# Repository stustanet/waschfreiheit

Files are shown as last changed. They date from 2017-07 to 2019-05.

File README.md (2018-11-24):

# Waschen in Freiheit !!!
## Was ist das?
Dieses Projekt soll verhindern, dass die armen Studenten unnötig lange mit der Suche nach einer freien Waschmaschine verbringen. Dazu soll der Status aller Maschinen erfasst werden um diese dann online abfragbar zu machen. Will man dann Waschen kann man direkt zu einer freien Maschine laufen und muss nicht erst in jedem Waschraum vorbeischauen, nur um festzustellen, dass dieser schon belegt ist.

## Aufbau
Der aktuelle Plan sieh in etwa so aus:

```
                                     +---+
+---Raum------------------------+    |   |
|                               |    | F |
|  WM <- Sensor  \              |    | U |
|                 => Knoten <~~~|~~~>| N |
|  WM <- Sensor  /              |    | K |
|                               |    |   |
+-------------------------------+    |   |
                                     |   |     +--------+    +-----------+
                                     |   |<~~~>| Bridge |--->| Webserver |
+---Raum------------------------+    |   |     +--------+    +-----------+
|                               |    |   |
|  WM <- Sensor  \              |    |   |
|                 => Knoten <~~~|~~~>|   |
|  WM <- Sensor  /              |    |   |
|                               |    |   |
+-------------------------------+    |   |
                                     |   |
                                     |   |
+---Raum------------------------+    |   |
|                               |    |   |
|  WM <- Sensor ===> Knoten <~~~|~~~>|   |
|                               |    |   |
+-------------------------------+    |   |
                                     +---+
    
```

### Sensoren
Ein Sensor misst den Stromverbrauch einer Maschine. Dies geschieht über einen Hallsensor am Stromkabel.

### Knoten
Ein Knoten besteht aus einem Mikroprozessor (STM32F103C8T6 (V1) oder STM32F401RBT6(V2), Kleiner 32bit ARM) und einem 433Mhz Funkchip (Sx1276, LoRa Modulation).
An einen Knoten sind ein oder mehrere Sensoren angeschlossen. Die Sensordaten werden dann ausgewertet und bei einer Statusänderung wird ein Signal über die Funkschnittstelle gesendet.
Außerdem ist es die Aufgabe eines Knotens Nachrichten anderer Knoten weiterzuleiten, diese bilden quasi ein Mesh Netzwerk.

### Bridge
Es gibt im ganzen System genau eine Bridge (Gateway, Master Node), diese besteht aus einem Funkteil und einem Raspi. Die Aufgabe der Bridge ist es die Statusänderungen vom Mesh Netzwerk zu empfangen und diese dann per IP an einen Webserver weiterzuleiten, der diese dann anzeigt. Zusätzlich verwaltet die Bridge das Netzwerk und die Sensorparameter.

### Webserver
Der Webserver bekommt die Daten von der Bridge und zeigt den aktuellen Status an.

## Statuserkennung
Die Statuserkennung basiert auf Messwerten, die ein am Stromkabel befestigter Hall-Sensor liefert.
Um aus diesen Werten schlussendlich zu erkennen ob eine Maschine in Benutzung ist, durchläuft das Signal eine Reihe von Filtern.

### Analoger Teil
#### Wechselspannungs-Verstärker
Zuerst wird das Signal vom Hall-Sensor verstärkt. Der Verstärker hat für DC einen Verstärkungsfaktor von 1, es werden also nur Änderungen verstärkt.
#### Tiefpass
Bevor das Signal vom ADC digitalisiert wird, wird es mit einem RC-Filter geglättet. Dieser Tiefpass darf nicht zu träge sein, eine höhere Trägheit die Amplitude verringert.

### Digitaler Filter, Stufe 1 (Input)
Die erste Stufe bekommt die Messwerte des ADCs, sie wird für jede Messung einmal aufgerufen.
#### Absolutwertbestimmung
Da das Signal eine Wechselspannung mit dem Mittelpunkt von ca. der halben Betriebsspannung ist, muss zuerst der Absolutwert (Abweichung vom Mittelwert) bestimmt werden.
Dazu wird ein Mittelwert bestimmt, der für jeden Messwert, der drüber liegt um einen kleinen Wert erhöht wird (bzw. verringert wird, wenn der Messwert niedrieger ist).
Die Differenz zwischen dem Mittelwert und dem aktuellen Messwert ist der Absolutwert.
#### Digitaler Tiefpass
Der Absolutwert wird über einen Digitalen Tiefpass geglättet. Hier ist eine wesentlich stärkere Glättung möglich als vor dem Absolutwertfilter, da keine Amplitude verloren geht.

### Digitaler Filter, Stufe 2 (Frames)
In bestimmten Abständen (Frames) wird der aktuelle Tiefpasswert der Stufe 1 an die Stufe 2 weitergegeben. Der Abstand ist die "Framesize"
Die Stufe 2 wird einmal pro Frame aktualisiert. Die letzten "Window Size" Frame-Werte werden gespeichert, aus diesen wird der aktuelle Wert des Filters berechnet.
#### Blockfilter (Consec reject filter)
Alle Werte die nicht größer als ein Grenzwert ("Reject Threshold") sind und nicht mind. "Reject Consec" Werte davor auch über dem Grenzwert liegen werden bei der Berechnung des aktuellen Wertes ignoriert.

Beispiel:
Angenommen der Threshold wäre 5 und der "Consec count" wäre 3, dann würden nur die markierten Werte verwendet werden.

    3 9 8 2 7 8 9 6 3 4 9 2 1 6 7 8 9 9 9 3 4 7 8 2
            ^ ^ ^ ^           ^ ^ ^ ^ ^ ^

#### Durchschnittswert
Der aktuelle Filterwert ist der Durchschnitt aller Werte im aktuellen Fenster. Werte die vom Blockfilter ignoriert werden gehen mit 0 in den Durchschnitt ein.
#### Interner Status
Abhängig vom aktuellen Filterwert und dem aktuellen internen Status wird anhand von festgelegten Grenzwerten bestimmt, ob ein Zustandsübergang stattfindet.
Bei einem Zustandsübergang wird ggf. die "Window Size" angepasst. Für jeden internen Zustand ist festgelegt, ob die Maschine in diesem Zustand belegt oder frei ist.
Nur Änderungen des Belegtzustandes werden über das Netzwerk gesendet.

## Ich will das complien!
* Ggf. ARM Toolchain installieren.
* Dieses Repo klonen.
* git submodule init
* git submodule update
* "make all" im Ordner firmware baut Master (V1 / V2), Sensor (V1 / V2) und den Bootloader (nur V2)

## Flashen
Es gibt eine Reihe verschiedener Möglichkeiten die Firmware zu flashen.
Manche sind nur auf V1 oder V2 verfügbar.

### ST-LINK
Die bequemste Möglichkeit diese Controller zu flashen ist ein ST-LINK. Dies ist ein spezieller Programmer / Debugger für ST Controller. Um einen ST-LINK zu verwenden muss OpenOCD installiert sein.

#### Benötigte Anschlüsse
Um mit einen ST-LINK zu flashen müssen folgende 3 / 4 Leitungen mit dem Board verbunden werden:
* GND
* SWIO
* SWCLK
* Ggf. 3.3V

Flashen geht dann einfach mit
```
Sensor V1
make flash_sv1

Sensor V2
make USE_BOOTLOADER=FALSE flash_sv2

Master V1
make flash_mv1

Master V2
make flash_mv2

Bootloader V2
make flash_blv2
```

### Serieller Bootloader
Das Board muss über ein Serielles Kabel mit dem PC verbunden werden.

Der flasher Tool stm32loader.py befindet sich als submodule in firmware/utils.

Das Kabel wird wie folgt angesteckt:
* RX von Kabel an TX vom Board
* TX von Kabel an RX vom Board
* GND an GND
* Ggf. die 5V von USB and die 5V(!) vom Board anschließen

Um das Board in den Bootloader Modus zu bringen:
#### V1
* Den BOOT0 Jumper auf 1 setzen
* Reset kurz drücken
* Nach dem Flashen den BOOT0 Jumper auf 0 zurüksetzen

#### V2
* Boot drücken und halten
* Reset kurz drücken
* Boot wieder loslassen

Zum flashen dann
```
Binary erstellen mit
arm-none-eabi-objcopy -I ihex -O binary <ELF> /tmp/image.bin

flashen mit
./stm32loader.py -p /dev/ttyUSB0 -evw /tmp/image.bin
```

### USB DFU Bootloader (Nur V2)

Dazu muss zuerst das tool dfu-util gebaut werden.
Dieses ist als submodule in firmware/utils eingebunden.

```
cd firmware/utils
./autogen.sh
./configure
make
```

Das Board wird dann über ein Micro-USB Kabel mit dem PC verbunden.
Um das Board in den Bootloader Modus zu bringen:
* Boot drücken und halten
* Reset kurz drücken
* Boot wieder loslassen

Dann sollte es sich am PC als DFU Gerät anmelden.
Zum flashen dann
```
Binary erstellen mit
arm-none-eabi-objcopy -I ihex -O binary <ELF> /tmp/image.bin

flashen mit
sudo ./dfu-util -a 0 -s 0x08000000:leave -D /tmp/image.bin
```

### USB Host Bootloader (Nur Sensor V2)
Der USB Host Bootloader ist ein eigener Bootloader für diese Boards, der es erlaubt ein Firmware image auf einen USB-Stick zu laden und dann ohne einen PC ein Update einzuspielen.
Um diesen zu verwenden, muss das Firmware Image für den Bootloader gebaut werden (ohne USE_BOOTLOADER=FALSE) und der Bootloader muss geflasht sein (das geht mit einer der anderen Methoden).

Auf einen FAT32 formatierten USB Stick müssen sich folgende Dateien befinden:
* FIRMWARE.BIN  Neue Firmware im Binärformat
* CHECKSUM.CRC  CRC32 Prüfsumme der Firmware

Diese beiden Dateien können bequem mit make_boot_files.sh in firmware/utils aus einer ELF erstellt werden.

Dann den Stick einfach an das Board anstecken und resetten. Die Eingangs-LEDs sollten während des Updates der Reihe nach in den Farben Grün, Violett, Rot und Gelb aufleuchten.
Nach dem Flashen wird das Programm normal gestartet.

Der USB Stick wird *nicht* erkannt, wenn dass Board über den Micro-USB Anschluss mit Strom versorgt wird.

### Flasher command (Nur V1)
Die V1 Boards haben einen integrierten Flash-Befehl mit dem die Firmware aus dem laufenden Betrieb heraus geupdated werden kann.
Da dazu nur die Serielle Schnittstelle benötigt wird und nicht extra ein Boot-Modus aktiviert werden muss ist dieser Modus praktisch um die alten Nodes zu flashen, da diese schlecht zu Öffnen sind.
Der Nachteil ist, dass sich der Flasher selbst überschreibt, d.h. sollte etwas schiefgehen, ist der Knoten über diesen Weg nicht erneut flashbar.

Das Tool zum flashen ist firmware/utils/flasher_v1.py

Zum flashen
```
Binary erstellen mit
arm-none-eabi-objcopy -I ihex -O binary <ELF> /tmp/image.bin

flashen mit
./flasher_v1.py /dev/ttyUSB0 /tmp/image.bin
```

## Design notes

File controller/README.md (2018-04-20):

# Waschen in Freiheit - Management Interface

This is the Waschmaschinen management interface implemented in python.
It takes care in setting up the network, monitoring the network, and, if
neccessary, recover it in order to keep all nodes running.

It is designed to connect directly via a serial interface to the master node.

## Getting started

Create a virtual environment and install the requirements into it.

```
python3 -m venv venv
. ./venv/bin/activate
pip install -r requirements.txt
```

Now set up the nodes as they are supposed to work within the json config.
The management node can now be started with: (set the config file and the
serial connection according to your local setup!)

```
python3 main.py --config ./nodes.json --serial /dev/ttyUSB0
```

Now the interface is booting up. Have fun!

## Testing

You do not have a real master at hand? Therefore we have a very simplified
tester that reacts like the real thing.
It exposes a serial interface via socat, feeding in one of three test cases:

- Everything is fine, your network will *just* work, always, be happy!
- Node 2 is broken! Oh noes! It will never respond to you.
- You network is really bad. 80% of all your messages will timeout. Deal wit it

These have proven quite valuable to evaluate network performance and possible
deadlocks before the real hardware (network setup time: 0.0016s vs. 40s)

## Configuring

The configuration is split into two types of files: the main config and the
sensor specifications.

### Main Config

Follow this example config:

```javascript
{
  // Number of times a retransmit should be tried before a node is assumed dead,
  // and a network recovery is started
  "retransmissionlimit": 3,
  // Time in seconds, how often a network check should be performed
  "networkcheckintervall": 600,
  // How much time does one step in the network take, at max (in seconds)
  "single_hop_timeout": 2,

  // Configuring the different nodes
  "nodes": [
    // Every setup _needs_ a node named 'MASTER', it will be used as entry point
    // into the route resolution.
    {
      // The ID given here has to match the hardware-id of the actual node!
      "id": 0,
      // This name is used for reference later
      "name":"MASTER",
      // What sensors are connected (not used on the master node)
      "channels": [],
      // Sample rate of the sensors (not used on the master node)
      "samplerate": 0,
      // How to reach which other node.
      "routes":{
        "HOUSEA-ROOM1":"HOUSEA-ROOM1",
      }
    },
    {
      // The ID given here has to match the hardware-id of the actual node!
      "id": 1,
      // This name is used for reference later (see it in the master-routing?)
      "name":"HOUSEA-ROOM1",
      // Samples taken for the connected sensors per second
      "samplerate": 500,
      // Which sensors are connected?
      "channels": [
        {
          // Channel Number 0 is always the left plug
          "number": 0,
          "name":"left",
          "model":"A",
          // additional sensor data for configuring the sensor
          "config": "sensor_normal.json"
        },
        {
          "number": 1,
          "name":"right",
          "model":"B",
          "config": "sensor_normal.json"
        }
      ],
      // How to reach back to the master
      "routes":{
        "MASTER":"MASTER",
      }
    },
  ]
}
```

### Sensor Config

The sensor configuration file describes the details coming from sensor and
machine.

```javascript
{
	"input_filter":
	{
		"mid_adjustment_speed": 20,
		"lowpass_weight": 50,
		"frame_size": 100
	},
	"transition_matrix": [
		[   0,    0,   80,    0],
		[ -24,    0,    0,  160],
		[ -48,    0,    0,  160],
		[   0,  -80,    0,    0]
	],
	"window_sizes": [
		150,
		1500,
		1500,
		1500
	],
	"reject_filter": {
		"threshold": 104,
		"consec_count": 15
	}
}
```

These need to be adjusted for any machine and sensor connected.

## Routing

The most important configuration to reach all nodes is routing.

Every message is routed independently, so the sending node has to know via
which gateway it can reach which node.

If you have a setup like this in your building, and you can only reach from ones
adjacent.

```
| - - - - |
| OG 30   |
| OG 20   |
| OG 10   |
| MASTER  |
| - - - - |
```

You have to configure for the master

```
{
  'OG 30':'OG 10',
  'OG 20':'OG 10',
  'OG 10':'OG 10'
}
```

that way you tell him, it can reach every room via `OG 10`.

If you did some tests, and fortunately can reach nodes `OG 10` and `OG 20` from master,
then you configure:

```
{
  'OG 30':'OG 20',
  'OG 20':'OG 20',
  'OG 10':'OG 10'
}
```

## Failure States

It is normal, that from time to time a message does not reach its destination
and the system therefore logs a lost message. thats why we do try it again.

If a node does not respond to multiple retries, we start reinitializing it
in the hope, that it just has had a hickup (like some power-outages).

If that does not succeed, we issue an error - because then it is most likely
that the node has died, or something is not fine with the RF.

In the case of multiple failures, always check in order of distance (in terms of
routes from the master), because nodes that live behind a gateway cannot be
reached, if the gateway is broken.

Since the nodes themselve assume they are dead or have forgotten their routes,
if they do not receive messages once in a while, the network should mostly be
self-healing.
Only if a node continues to be dead, a manual restart or replacement might be
required.

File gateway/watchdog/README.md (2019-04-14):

# Serial watchdog
This is a watchdog running on a Atmel/Microchip AVR microcontroller, that listens on a serial port for a specific watchdog reset message:
```
wdt_feed
```

This resets the internal watchdog timer.
Otherwise, if the watchdog timer expires, it sets an output to HIGH in order to reset a connected device.
Some time before the reset, a PREFAIL signal is asserted, in order to notifiy the connected device, that the reset by the watchdog is imminent.

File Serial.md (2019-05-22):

# Serielles Interface

## Allgemeine Befehle

#### routes DST1:HOP1,DST2:HOP2,...
Setzt die routen die vom Aktuellen Knoten verwendet werden.
* DSTn:HOPn Pakete für DSTn werden an HOPn weitergeleitet.

Dieser Befehl ist auf den Sensorknoten nur zu testzwecken verfügbar. Diese Knoten bekonnen ihre Routen normalerweie über das Netzwerk vom Master.

#### ping NODE\_ID
Sendet einen Echo-Request an einen Knoten.
* NODE\_ID Adresse des Knotens.

Damit der Reply auch ankommt, muss eine aus beiden Richtungen gültige Route existieren.

## Sensor
Der Sensor kennt aktuell nur einen Befehl:
#### config NODE\_ID KEY\_STATUS KEY\_CONFIG
Ändert die Netzwerk-Configuration eines Sensorknotens.
* NODE\_ID ist die Adresse dieses Knotens. Eine Adresse darf nur einmal vergeben werden.
* KEY\_STATUS ist der Gemeinsame Schlüssel der für den Status-Kanal verwendet wird.
* KEY\_CONFIG ist der Gemeinsame Schlüssel der für den Konfigurations-Kanal verwendet wird.
* Beide Schlüssel sind 16 Byte lang und werden als Hex angegeben.

## Master
Der Master spricht ein gemischtes (Mensch- und Maschinenlesbares) Protokoll.
Dazu gibt es zusätzlich zu den "normalen" Befehlen spezielle Nachrichten die vom Knoten gesendet werden um den Host über Statusänderungen und Ergebnisse von Befehlen zu informieren.
Diese werden im folgenden Updates genannt.
Es darf immer nur einen Ausstehenden Befehl pro Node geben, dieser muss erst ACK'ed werden (ACK update) bevor der Nächste gesendet wird.
Die einzigen Ausnahmen sind master\_routes, ping und connect.

### Befehle

#### connect NODE\_ID RETURN\_HOP TIMEOUT
Stellt eine Verbindung zu einem Knoten her.
* NODE\_ID Adresse des Knotens zu dem die Verbindung aufgebaut werden soll.
* RETURN\_HOP Erster Knoten auf dem Rückweg (Pfad von NODE\_ID zum Master). Dies wird als temporäre Route verwendet bis die vollständigen Routen gesetzt wurden.
* TIMEOUT Ist die länge des timeouts. Nach der angegebenen Zeit wird ds TIMEOUT Update gesendet und retransmit darf aufgerufen werden.

#### retransmit NODE\_ID
Sendet das letzte Paket für einen Knoten erneut.
* NODE\_ID Adresse des Knotens

Dies darf nur aufgerufen erden, nachdem ein Knoten einen TIMEOUT gemeldet hat.

#### reset\_routes NODE\_ID DST1:HOP1,DST2,HOP2,...
#### set\_routes NODE\_ID DST1:HOP1,DST2,HOP2,...
Setzt / Ändert die Routen eines Knotens. reset\_routes setzt dabei zuerst den Knoten (incl. aller Routen und Sensoreinstellungen) zurück. add\_routes ändert nur die bestehenden Routen.
* NODE\_ID Adresse des Knotens der Konfiguriert wird. Bevor ein Knoten konfiguriert wird, muss eine Verbindung (connect) aufgebaut werden.
* DSTn:HOPn Pakete für DSTn werden an HOPn weitergeleitet. Es können pro Aufruf maximal 20 Routen angegeben werden.

Die Route die bei connect angegeben wurde muss hier erneut spezifiziert werden.

#### configure\_sensor NODE\_ID CHANNEL INPUT\_FILTER ST\_MATRIX WND\_SIZES REJECT\_FILTER
Ändert die Konfiguration eines Sensors. Genauere Informationen zu den Parametern finden sich im state\_estimation haeder.
* NODE\_ID Adresse des Knotens der Konfiguriert wird.
* CHANNEL Nummer des Sensor-Kanals der Konfiguriert wrid.
* INPUT\_FILTER 3 Werte (uint16): MID\_ADJUSTMENT,LOWPASS\_WEIGHT,NUM\_SAMPLES
* ST\_MATRIX 12 Werte (int16), Bedingungen für Zustandsübergänge.
* WND\_SIZES 4 Werte (uint16, max 1536), Festergrößen in den entsperchenden Zuständen.
* REJECT\_FILTER 2 Werte (uint16) REJECT\_THRESHOLD,REJECT\_CONSEC

#### enable\_sensor NODE\_ID CHANNEL\_MASK SAMPLES\_PER\_SEC
Startet / Aktiviert die Sensoren.
* NODE\_ID Adresse des Knotens der Konfiguriert wird.
* CHANNEL\_MASK Bitfeld, ein gesetztes Bit steht für einen aktiven Sensor.
* SAMPLES\_PER\_SEC Sampling-Rate des ADCs, diese gilt für alle Sensoren.

#### raw\_frames NODE\_ID CHANNEL NUM\_OF\_FRAMES
Fragt Sensordaten von einem Knoten an. Das ist nur zum Kalibrieren des Sensors gedacht.
* NODE\_ID Adresse des Knotens.
* CHANNEL Sensorkanal
* NUM\_OF\_FRAMES Anzahl an Frames zum Senden.

#### authping NODE\_ID
Fragt an ob ein Knoten noch aktiv ist.
* NODE\_ID Adresse des Knotens.

### Updates / Signale
Updates haben das Prefix ### um diese leicht zu parsen.
#### ACK\<ID\>-\<CODE\>
Eine Netzwerk-Anfrage an Knoten ID wurde bestätigt. CODE ist der ACK-Code, dieser ist Abhängig vom Request. 0 oder 128 bedeuten, dass die Anfrage erfolgreich war.
Nach einem ACK kann an den Node ID der nächste Befehl gesendet werden.
#### ERR
Der letzte Befehl war ungültig. Es braucht nicht auf ein ACK gewartet werden.
#### TIMEOUT\<ID\>
Es ist ein Timeout aufgetreten. Es sollte deshalb bei Zeiten für diesen Knoten einen retransmit Aufruf geben. Dieser kann entweder direkt nach dem Timeout kommen oder zwischen durch kann auch noch anderes gemacht werden.
#### STATUS\<ID\>-\<STATUS\>
Statusupdate von Knoten ID. Status ist ein Bitfeld, ein gesetztes Bit steht für eine Aktive Maschine.
#### PEND\<ID\>
Ein PEND Signal kommt als direkte Antwort auf einen Befehl, falls ein Packet versendet wurde welches bestätigt werden muss. Daher folgt auf ein PEND immer ein ACK oder ein TIMEOUT.

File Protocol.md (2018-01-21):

# Nachrichten und Routing
## Übersicht
Die Schichten sind an das OSI Modell angelehnt.

### Physical Layer (Layer 1)
Für den Datentransport wird 433MHz Funk mit LoRa Modulation verwednet. Alle Knoten senden und empfangen auf der selben Frequenz.

### Data Link Layer (Layer 2)
Die Verwendeten Funkmdule (Sx127x) kümmern sich bereits um das Verpacken der Daten in Pakete. Jedes Paket besitzt eine CRC Prüfsumme und eine Längenangabe (unterschiedlich lange Pakete sind also möglich),

### Network / Routing Layer (Layer 3)

Jeder Knoten hat eine eindeutige Adresse, alle Pakete haben folgende drei Knoten-Adressen:
* Quelle
* Ziel
* Next-Hop

Die Quelladresse ist dabei die Adresse des ursprünglichen Senders, die Zieladresse die des finalen Ziels. Next-Hop ist die Adresse des Knotens, der dieses Paket empfangen soll um es dann entweder zu verarbeiten (Next-Hop == Ziel) oder weiterzuleiten (Ziel in der Routing-Tabelle suchen und mit dem / an den entsprechendem Next-Hop weitersenden).
Eine Adressse ist eine 8-bit Zahl.

### Payload type (Layer 4)
(Jetzt nicht mehr OSI)
Typ-ID der Payload.
Je nach Typ wird auch ein MAC über den Layer4 (type + data) + Source und Destiantion Adresse gebiltet.

### Payload data (Layer 5)
(optional)
Je nach Payload-Typ unterschiedliche Daten.

## Aufbau des Netzwerks
### Master node
Der Koordinator (Master) hat die Aufgabe das Netzwerk aufzubauen und zu verwalten und dient gleichzeitig als Gateway zwischen dem Funk-Netz und dem Internet.
Der Master besitzt normalerweise die Adresse 0, da diese für einen Sensor ungültig ist.
Das Routing ist (vorest) statisch, aber zentral verwaltet, d.h. der Master kennt alle Knoten (diese sind in seiner config festgelegt) und alle Routing-Tabelle der Knoten (ebenfalls aus config).
Zum Initialisieren des Netzes werden nacheinander die Knoten vom Master aus angesprochen und die Routing-Tabellen der Knoten konfiguriert. Diese Verbinung wird ggf. über bereits konfigurierte Knoten (wenn das Ziel weiter weg ist) geroutet.
Nach dieser Initialisierung hat jeder Knoten eine (hoffentlich gültige und sinvolle) Routing-Tabelle und weis somit wohin er eine Nachricht die bei ihn ankommt weiterleiten soll.

### Acknowledgements
Es gibt keine allgemeinen Acknowledgements, jedoch müssen Nachrihten die signiert sind bestätigt werden. Dazu wird ein signiertes Ack Paket zurück gesendet.

### Aufbau eines Layer 3 Pakets
Layer 3 ist das Routing-Layer und das niedrigste Layer um das sich der Node kümmert.
Wenn ein Paket weitergeleitet wird, wird nur der Next-Hop geändert und das Paket ansonsten unverändert erneut gesendet.

Die Zahl in Klammern ist die Bit-Anzahl des jeweiligen Feldes.

```
+--------------+
| Next-Hop (8) |
|--------------|
| Ziel     (8) |
|--------------|
| Quelle   (8) |
|--------------|
|              |
| Layer 4  (n) |
|              |
+--------------+
```

### Authentication Protocol
A und B besitzen einen gemeinsamen Geheimen Schlüssel. Eine Verbndung ist nur unidirektional, für eine Verbindung in die andere Richtung muss ein zweiter Kanal (mit einem anderen Schlüssle aufgebaut werden.)

A möchte eine Verbindung aufbauen um Daten nach B zu übertragen, sodass B sicher sein kann, dass diese von A kommen.
(z.B. A möchte die Konfiguration von B ändern).

```
A                                      B
|                                      |
|----------> REQ_NONCE, M ------------>|
|                                      |
|<--------- N, M, MAC(N, M) -----------|
|                                      |
|---- CMD, N + 1, MAC(CMD, N + 1) ---->|
|                                      |
|<--- ACK, N + 2, MAC(ACK, N + 2) -----|
|                                      |
|---- CMD, N + 3, MAC(CMD, N + 3) ---->|
|                                      |
|<--- ACK, N + 4, MAC(ACK, N + 4) -----|
|                                      |
                                      
```

### Aufbau eines Layer 4 Pakets
Anhand der Payload-ID wird entschieden was für Daten das Paket enthält und ob es eine MAC hat.
Die nonce in der Nachricht ist die letzten 4 bit der aktuellen nonce. Dies wird verwendet um retransmissions schnell
zu erkennen.

```
+---------------------*
| Payload-ID (8)      |
|---------------------|
|                     |
| Layer 5 / Daten (n) |
|                     |
|---------------------|
| [Nonce (4)]         |
|---------------------|
| [MAC (60)]          |
+---------------------+
```

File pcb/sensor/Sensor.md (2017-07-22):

Das Funktionsprinzip der Sensoren ist das einer Stromzange, die Messung beruht darauf, dass ein Stromdurchflossener Leiter ein Magnetfeld erzeugt welches dann von einem Hallsensor gemessen werden kann.
Dabei wird um das Kabel ein Ferritkern gelegt, dieser hat einen Spalt, in den dann der eigentliche Sensor gesteckt wird.

Als Sensoren werden die analogen Hallsensoren "49E" verwendet. Diese Sensoren sollten bei keinem Magnetfeld eine Ausgangsspannung von exakt der halben Betriebsspannung liefern. Wenn sind das Magnetfeld ändert, ändert sich auch die Ausgangsspannung (ca. 1.8 mV / G).
Damit mit diesen am ADC des Mikroprozessors auch bei geringen Strömen ein sinnvoller Ausschlag messbar ist muss das Ausgangssignal noch zusätzlich verstärkt werden.
Der aktuelle Entwurf für diesen Verstärker ist ein Wechselspannungsverstärker, der nur Änderungen verstärkt und für Gleichspannung einen Verstärkungsfaktor von 1 hat.
Das hat den Vorteil, dass eventuelle Offsets der Sensorspannung nicht so sehr stören, leider ist diese Konstruktion jedoch sehr empfindlich gegenüber Störungen auf der Versorgungsspannung, hier besteht also noch Verbesserungspotential.
Eine einfache Konstruktion, die die Differenz von der Sensorspannung und der halben Betriebsspannung verstärkt, ist allerdings nicht möglich, da die Sensoren nicht *genau* die halbe Betriebsspannung liefern, wenn kein Magnetfeld da ist.
Diese Abweichung ist so groß, dass diese (bei dem gewünschten Verstärkungsfaktor) nicht einfach in Software korrigierbar ist.

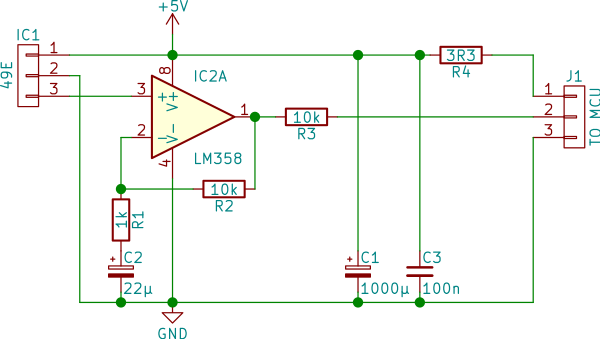
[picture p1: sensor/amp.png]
Schaltplan


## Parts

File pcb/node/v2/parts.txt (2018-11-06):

MCU: STM32F401RBT6
USB Switch: MIC2005A-1YM5-TR
Pluggable Terminal blocks

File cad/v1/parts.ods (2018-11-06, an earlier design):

# Räume | 4
Bauteileliste | #Pro raum | #Total | #Done | #Missing | Time/Part[h] | Time | Total printing time
ELEKTRONIK
Node-Platine | 1 | 4 | 3 | 1 | 2 | 2
Sensor-Platine | 2 | 8 | 8 | 0 | 1 | 0
3D PRINTS
SENSOR
Sensor-Bottom | 2 | 8 | 8 | 0 | 0,35 | 0 | 2,8
Sensor-Top | 2 | 8 | 8 | 0 | 1 | 0 | 8
Sensor-Wirecap | 2 | 8 | 8 | 0 | 0,25 | 0 | 2
Sensor-Wiresupport | 4 | 16 | 4 | 12 | 0,1 | 1,2 | 1,6
NODE
Node-Bottom | 1 | 4 | 3 | 1 | 2,25 | 2,25 | 9
Node Top | 1 | 4 | 3 | 1 | 4,5 | 4,5 | 18
Node LED Backplate | 1 | 4 | 4 | 0 | 0,75 | 0 | 3
Node LED Cover | 5 | 20 | 20 | 0 | 0,04 | 0 | 0,8
Wall distance | 3 | 12 | 12 | 0 | 0,04 | 0 | 0,48
 |  |  |  |  |  | 7,95 | 45,68
 |  |  |  |  |  | PER ROOM | 11,42

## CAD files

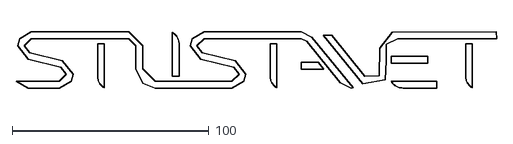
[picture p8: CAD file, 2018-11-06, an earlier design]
cad/v1/logo.dxf
244.2 x 28.5

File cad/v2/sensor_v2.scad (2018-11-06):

$fn=100;

epsilon = 0.003;

//TODO: Check params
power_cable_dia = 3.5;
ferrite_outer_dia = 10.4;
ferrite_depth = 5.3;
ferrite_width = 2.2;

pcb_size = [14, 11.5, 5];
pcb_cable_guide_width = 5;
pcb_cable_guide_extra_height = 4;
sensor_left_offset = 1;
sensor_height_offset = 2.3;
sensor_pin_size = [3, 0.8, 0.5];
sensor_head_size = [4.1, 3.2, 1.6];
sensor_head_z_pos = -0.3;

data_cable_dia = 4.1;
data_cable_x = 12;
data_cable_y = 5;
data_cable_zip_dist = -0.3;

base_sx = 21;
base_sy = 17;

base_border = [4, 2, 3.5];
base_edge_width = 1;
base_edge_heigth = 1;
base_cutout_x = 4;
base_cutout_y = 11;

top_thickness = 6;

zip_size = [1.4, 2.9];

// Derived parameters
pcb_to_sensor_center = [0, pcb_size[1], 0] + [sensor_left_offset + sensor_pin_size[0] / 2, sensor_pin_size[1], sensor_height_offset + sensor_head_z_pos] + [0, sensor_head_size[1] / 2, sensor_head_size[2] / 2];

ferrite_center = pcb_to_sensor_center - [ferrite_outer_dia / 2 - ferrite_width / 2, 0, 0];

base_size = [base_sx + base_border[0] * 2, base_sy + base_border[1] * 2, base_border[2] + ferrite_center[2]];

module ferrite()
{
    //difference()
    {
        cylinder(h = ferrite_depth, r = ferrite_outer_dia / 2, center = true);
        cylinder(h = ferrite_depth + epsilon, r = ferrite_outer_dia / 2 - ferrite_width, center = true);
    }
}

module power_cable()
{
    cylinder(h = 100, r = power_cable_dia / 2, center = true);
}

module pcb()
{
    
    cube(pcb_size);
    
    translate([0, 0, -pcb_cable_guide_extra_height / 2])
        cube([pcb_size[0], pcb_cable_guide_width, pcb_size[2] + pcb_cable_guide_extra_height]);
    translate([sensor_left_offset, pcb_size[1], sensor_height_offset])
    {
        cube(sensor_pin_size);
        translate([(sensor_pin_size[0] - sensor_head_size[0]) / 2, sensor_pin_size[1], sensor_head_z_pos])
        {
            cube(sensor_head_size);
        }
    }
}

module data_cable()
{
    cylinder(h = 100, r = data_cable_dia / 2);
}


module base_edge()
{
    translate([-epsilon/2, -epsilon/2, base_size[2] - base_edge_heigth + epsilon])
    {
        // normal edges
        translate([0, base_cutout_y - epsilon, 0])
            cube([base_edge_width + epsilon, base_size[1] - base_cutout_y + epsilon, base_edge_heigth]);
        
        translate([base_size[0] - base_edge_width, 0, 0])
            cube([base_edge_width + epsilon, base_size[1] + epsilon, base_edge_heigth]);
        
        translate([base_cutout_x - epsilon, 0, 0])
            cube([base_size[0] - base_cutout_x + epsilon, base_edge_width + epsilon, base_edge_heigth]);
        
        translate([0, base_size[1] - base_edge_width, 0])
            cube([base_size[0] + epsilon, base_edge_width + epsilon, base_edge_heigth]);
        
        // cutout edges
        translate([base_cutout_x - epsilon, 0, 0])
            cube([base_edge_width + epsilon, base_cutout_y, base_edge_heigth]);
        
        translate([base_edge_width, base_cutout_y - epsilon, 0])
            cube([base_cutout_x, base_edge_width + epsilon, base_edge_heigth]);
    }
}


module base()
{
    translate([pcb_size[0] - base_size[0] + base_border[0],
               -base_border[1],
               -base_border[2]])
    {
        difference()
        {
            cube(base_size);
            
            translate([-epsilon, -epsilon, -epsilon/2])
                cube([base_cutout_x, base_cutout_y, base_size[2] + epsilon]);
            
            base_edge();
        }
    }
}


module top()
{
    translate([pcb_size[0] - base_size[0] + base_border[0],
               -base_border[1],
               -base_border[2] + base_size[2]])
    {
        difference()
        {
            cube([base_size[0], base_size[1], top_thickness]);
            
            translate([-epsilon, -epsilon, -epsilon/2])
                cube([base_cutout_x, base_cutout_y, top_thickness + epsilon]);
        }
    }
        
    translate([pcb_size[0] - base_size[0] + base_border[0],
           -base_border[1],
           -base_border[2]])
    {
        base_edge();
    }
}


module zip_tie()
{
    translate([0, 0, -10])
    {
        cube([zip_size[0], zip_size[1], 25]);
    }
}

module bottom_only_zip_tie()
{
    translate([0, 0, ferrite_center[2] - 10 + epsilon])
    {
        cube([zip_size[0], zip_size[1], 10]);
    }
}

module zip_ties()
{
    translate([ferrite_center[0] - power_cable_dia, 3, 0]) zip_tie();
    translate([pcb_size[0] + 1, 3, 0]) zip_tie();
    
    translate([-9, ferrite_center[1] - zip_size[1] / 2, 0]) zip_tie();
    translate([5.5, ferrite_center[1] - zip_size[1] / 2, 0]) zip_tie();
    
    
    // zip ties for the data cable
    
    translate([data_cable_x - data_cable_dia / 2 - zip_size[0], ferrite_center[1] - zip_size[1] / 2, 0])
    {
        translate([-data_cable_zip_dist, 0, 0])
        bottom_only_zip_tie();
        
        translate([data_cable_dia + data_cable_zip_dist + zip_size[0], 0, 0]) bottom_only_zip_tie();
        
        // cutout in the top part for the data cable zip tie
        translate([0, 0, ferrite_center[2] + epsilon])
        cube([data_cable_dia + zip_size[0] * 2, zip_size[1], data_cable_dia / 2 + zip_size[0] + 1]);
    }
}


module components()
{
    pcb();

    translate(ferrite_center)
    rotate([90, 0, 0])
    {
        ferrite();
        power_cable();
    }
    
    translate([data_cable_x, data_cable_y, ferrite_center[2]])
    rotate([90, 0, 180])
    {
        data_cable();
    }
    
    zip_ties();
}


difference()
{
    base();
    %top();
    #components();
}

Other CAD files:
cad/v1/sensor_wall_plate.scad
cad/v1/cable.scad
cad/v1/casing.scad
cad/v1/distance_wall.scad
cad/v1/main_casing.scad

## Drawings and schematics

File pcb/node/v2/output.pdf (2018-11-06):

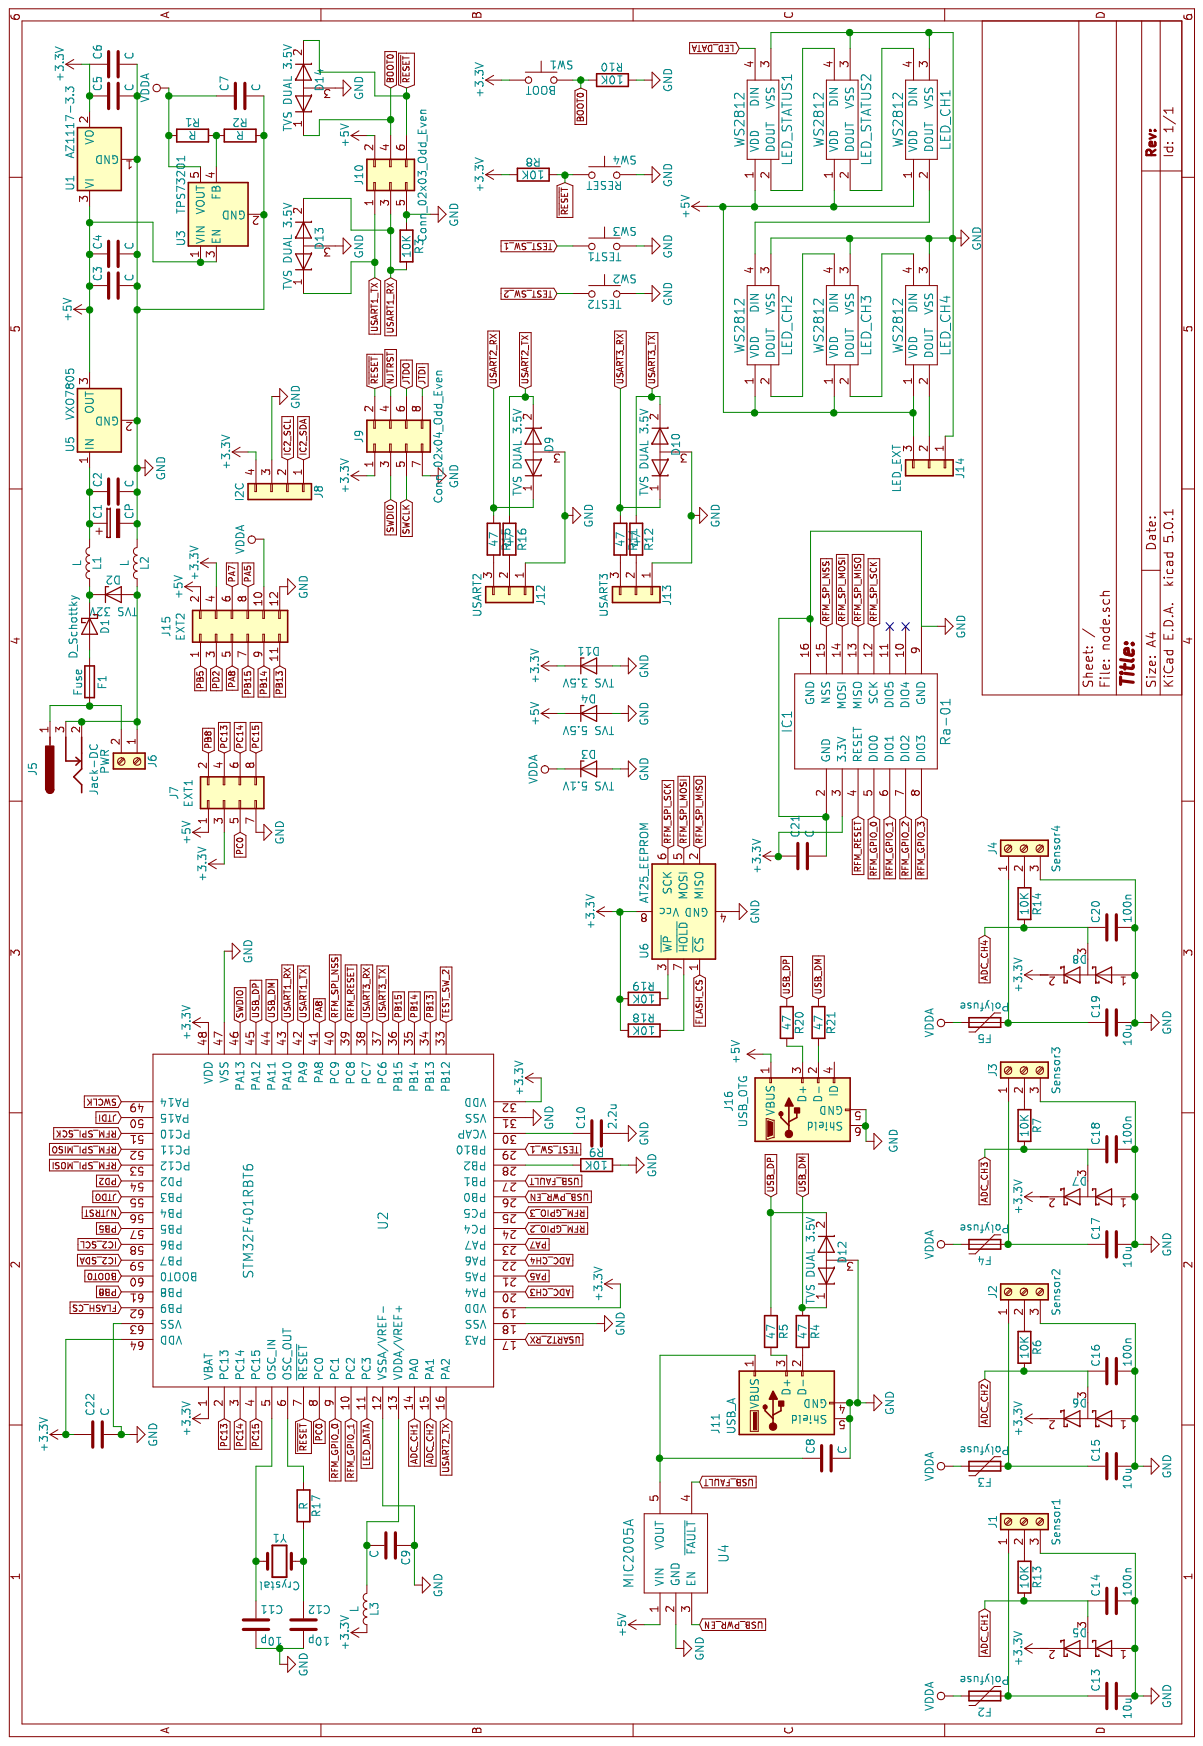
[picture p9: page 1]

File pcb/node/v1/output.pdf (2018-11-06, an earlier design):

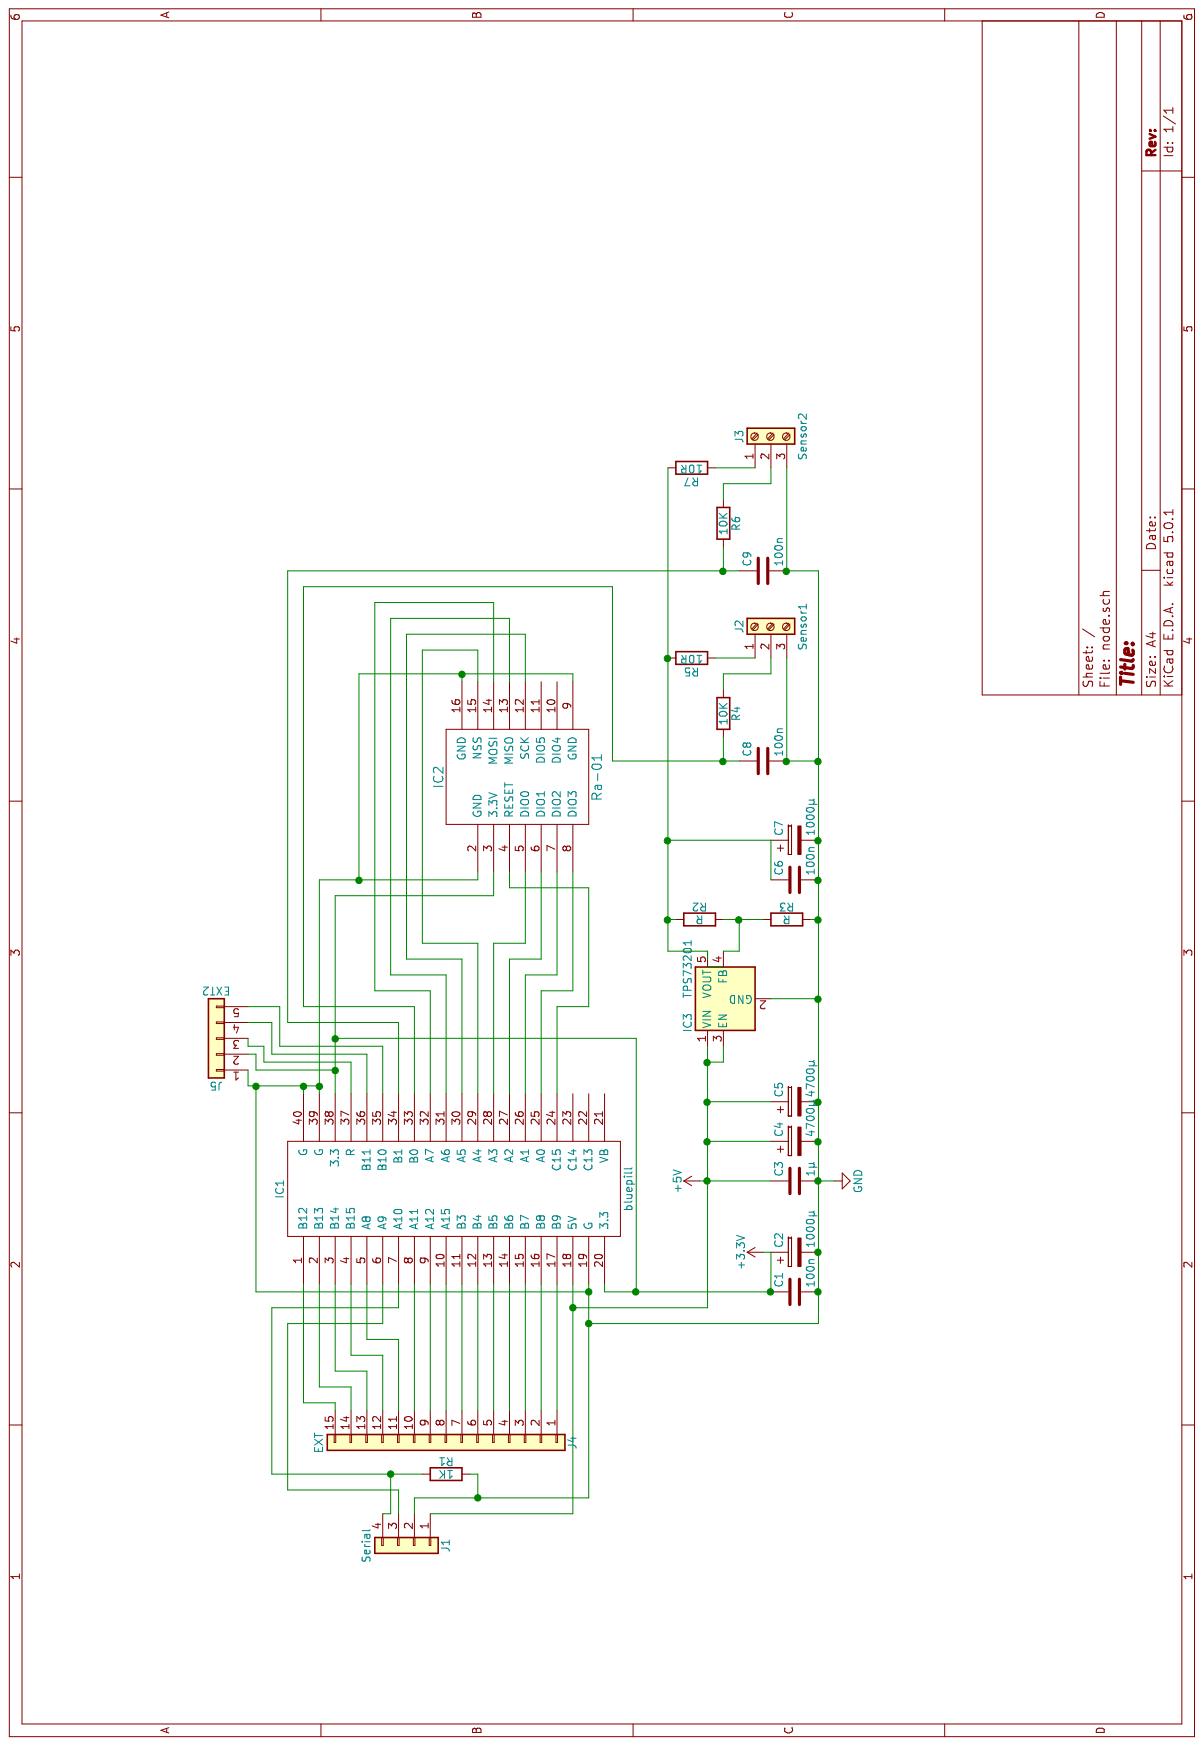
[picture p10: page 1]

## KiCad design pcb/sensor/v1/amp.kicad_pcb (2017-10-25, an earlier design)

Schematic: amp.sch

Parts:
C1: 1000µ; CP_Radial_D10.0mm_P5.00mm
C2: 22µ; CP_Radial_D5.0mm_P2.00mm
C3: 100n; C_Disc_D5.0mm_W2.5mm_P5.00mm
IC1: 49E; TO-92_Inline_Narrow_Oval
IC2: LM358; SOIC-8-N
J1: TO MCU; Pin_Header_Straight_1x03_Pitch2.54mm
R1: 1K; R_0805
R2: 10K; R_0805
R3: 4K7; R_0805
R4: 3R3; R_0805

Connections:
+5V: C1.1, C3.1, IC1.1, IC2.8 (V+), R4.2
GND: C1.2, C2.2, C3.2, IC1.2, IC2.4 (V-), J1.3
unnamed: C2.1, R1.2
unnamed: IC1.3, IC2.5 (+)
unnamed: IC2.6 (-), R1.1, R2.2
unnamed: IC2.7, R2.1, R3.2
unnamed: J1.1, R3.1
unnamed: J1.2, R4.1

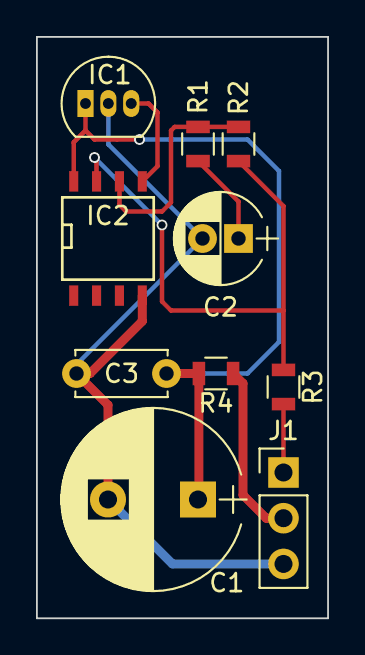
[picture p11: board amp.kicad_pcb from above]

Board: 2 copper layers, 16.2 x 32.3 mm, 10 parts (0 on the bottom side), 8 nets.

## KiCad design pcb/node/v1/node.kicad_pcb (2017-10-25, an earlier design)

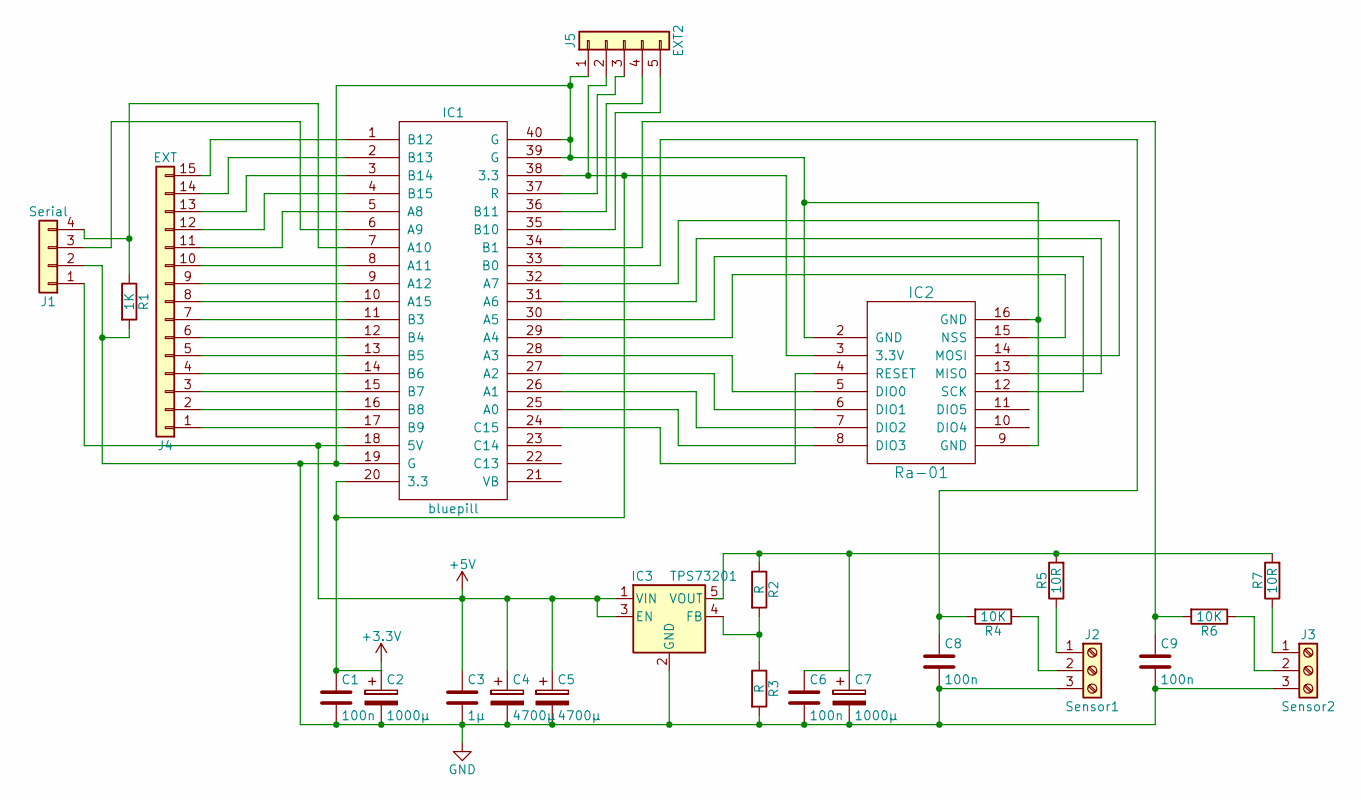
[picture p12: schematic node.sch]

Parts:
C1, C6, C8, C9: 100n; C_Disc_D5.0mm_W2.5mm_P2.50mm
C2, C7: 1000µ; CP_Radial_D10.0mm_P5.00mm
C3: 1µ; C_Disc_D7.5mm_W5.0mm_P5.00mm
C4, C5: 4700µ; CP_Radial_D12.5mm_P5.00mm
IC1: bluepill; DIP-40_W15.24mm
IC2: Ra-01
IC3: TPS73201; SOT-23-5
J1: Serial; Pin_Header_Straight_1x04_Pitch2.54mm
J2: Sensor1; TerminalBlock_Philmore_TB133_03x5mm_Straight
J3: Sensor2; TerminalBlock_Philmore_TB133_03x5mm_Straight
J4: EXT; Pin_Header_Straight_1x15_Pitch2.54mm
J5: EXT2; Pin_Header_Straight_1x05_Pitch2.54mm
R1: 1K; R_Axial_DIN0309_L9.0mm_D3.2mm_P12.70mm_Horizontal
R2, R3: R; R_0805
R4, R6: 10K; R_Axial_DIN0309_L9.0mm_D3.2mm_P12.70mm_Horizontal
R5, R7: 10R; R_Axial_DIN0309_L9.0mm_D3.2mm_P12.70mm_Horizontal

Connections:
+3V3: C1.1, C2.1, IC1.20 (3.3), IC1.38 (3.3), IC2.3 (3.3V), J5.2
+5V: C3.1, C4.1, C5.1, IC1.18 (5V), IC3.1 (VIN), IC3.3 (EN), J1.1
GND: C1.2, C2.2, C3.2, C4.2, C5.2, C6.2, C7.2, C8.2, C9.2, IC1.19 (G), IC1.39 (G), IC1.40 (G), IC2.2 (GND), IC2.9 (GND), IC2.16 (GND), IC3.2 (GND), J1.2, J2.3, J3.3, J5.1, R1.2, R3.2
unnamed: C6.1, C7.1, IC3.5 (VOUT), R2.1, R5.2, R7.2
unnamed: C8.1, IC1.33 (B0), R4.2
unnamed: C9.1, IC1.34 (B1), R6.2
unnamed: IC1.1 (B12), J4.15
unnamed: IC1.2 (B13), J4.14
unnamed: IC1.3 (B14), J4.13
unnamed: IC1.4 (B15), J4.12
unnamed: IC1.5 (A8), J4.11
unnamed: IC1.6 (A9), J1.3
unnamed: IC1.7 (A10), J1.4, R1.1
unnamed: IC1.8 (A11), J4.10
unnamed: IC1.9 (A12), J4.9
unnamed: IC1.10 (A15), J4.8
unnamed: IC1.11 (B3), J4.7
unnamed: IC1.12 (B4), J4.6
unnamed: IC1.13 (B5), J4.5
unnamed: IC1.14 (B6), J4.4
unnamed: IC1.15 (B7), J4.3
unnamed: IC1.16 (B8), J4.2
unnamed: IC1.17 (B9), J4.1
unnamed: IC1.24 (C15), IC2.4 (RESET)
unnamed: IC1.25 (A0), IC2.8 (DIO3)
unnamed: IC1.26 (A1), IC2.7 (DIO2)
unnamed: IC1.27 (A2), IC2.6 (DIO1)
unnamed: IC1.28 (A3), IC2.5 (DIO0)
unnamed: IC1.29 (A4), IC2.15 (NSS)
unnamed: IC1.30 (A5), IC2.12 (SCK)
unnamed: IC1.31 (A6), IC2.13 (MISO)
unnamed: IC1.32 (A7), IC2.14 (MOSI)
unnamed: IC1.35 (B10), J5.5
unnamed: IC1.36 (B11), J5.4
unnamed: IC1.37 (R), J5.3
unnamed: IC3.4 (FB), R2.2, R3.1
unnamed: J2.1, R5.1
unnamed: J2.2, R4.1
unnamed: J3.1, R7.1
unnamed: J3.2, R6.1

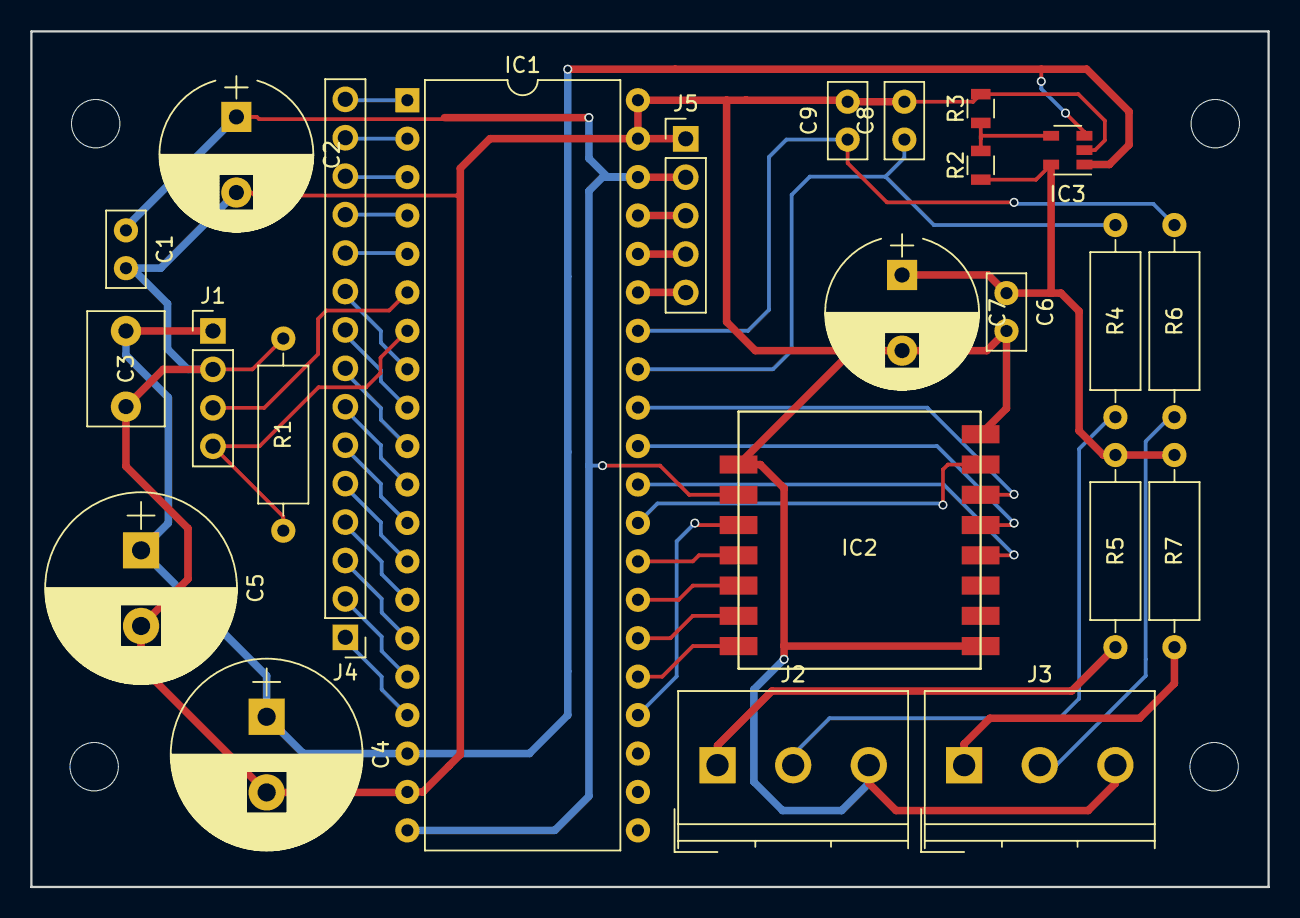
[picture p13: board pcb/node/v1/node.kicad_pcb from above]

Board: 2 copper layers, 81.8 x 56.5 mm, 24 parts (0 on the bottom side), 40 nets.

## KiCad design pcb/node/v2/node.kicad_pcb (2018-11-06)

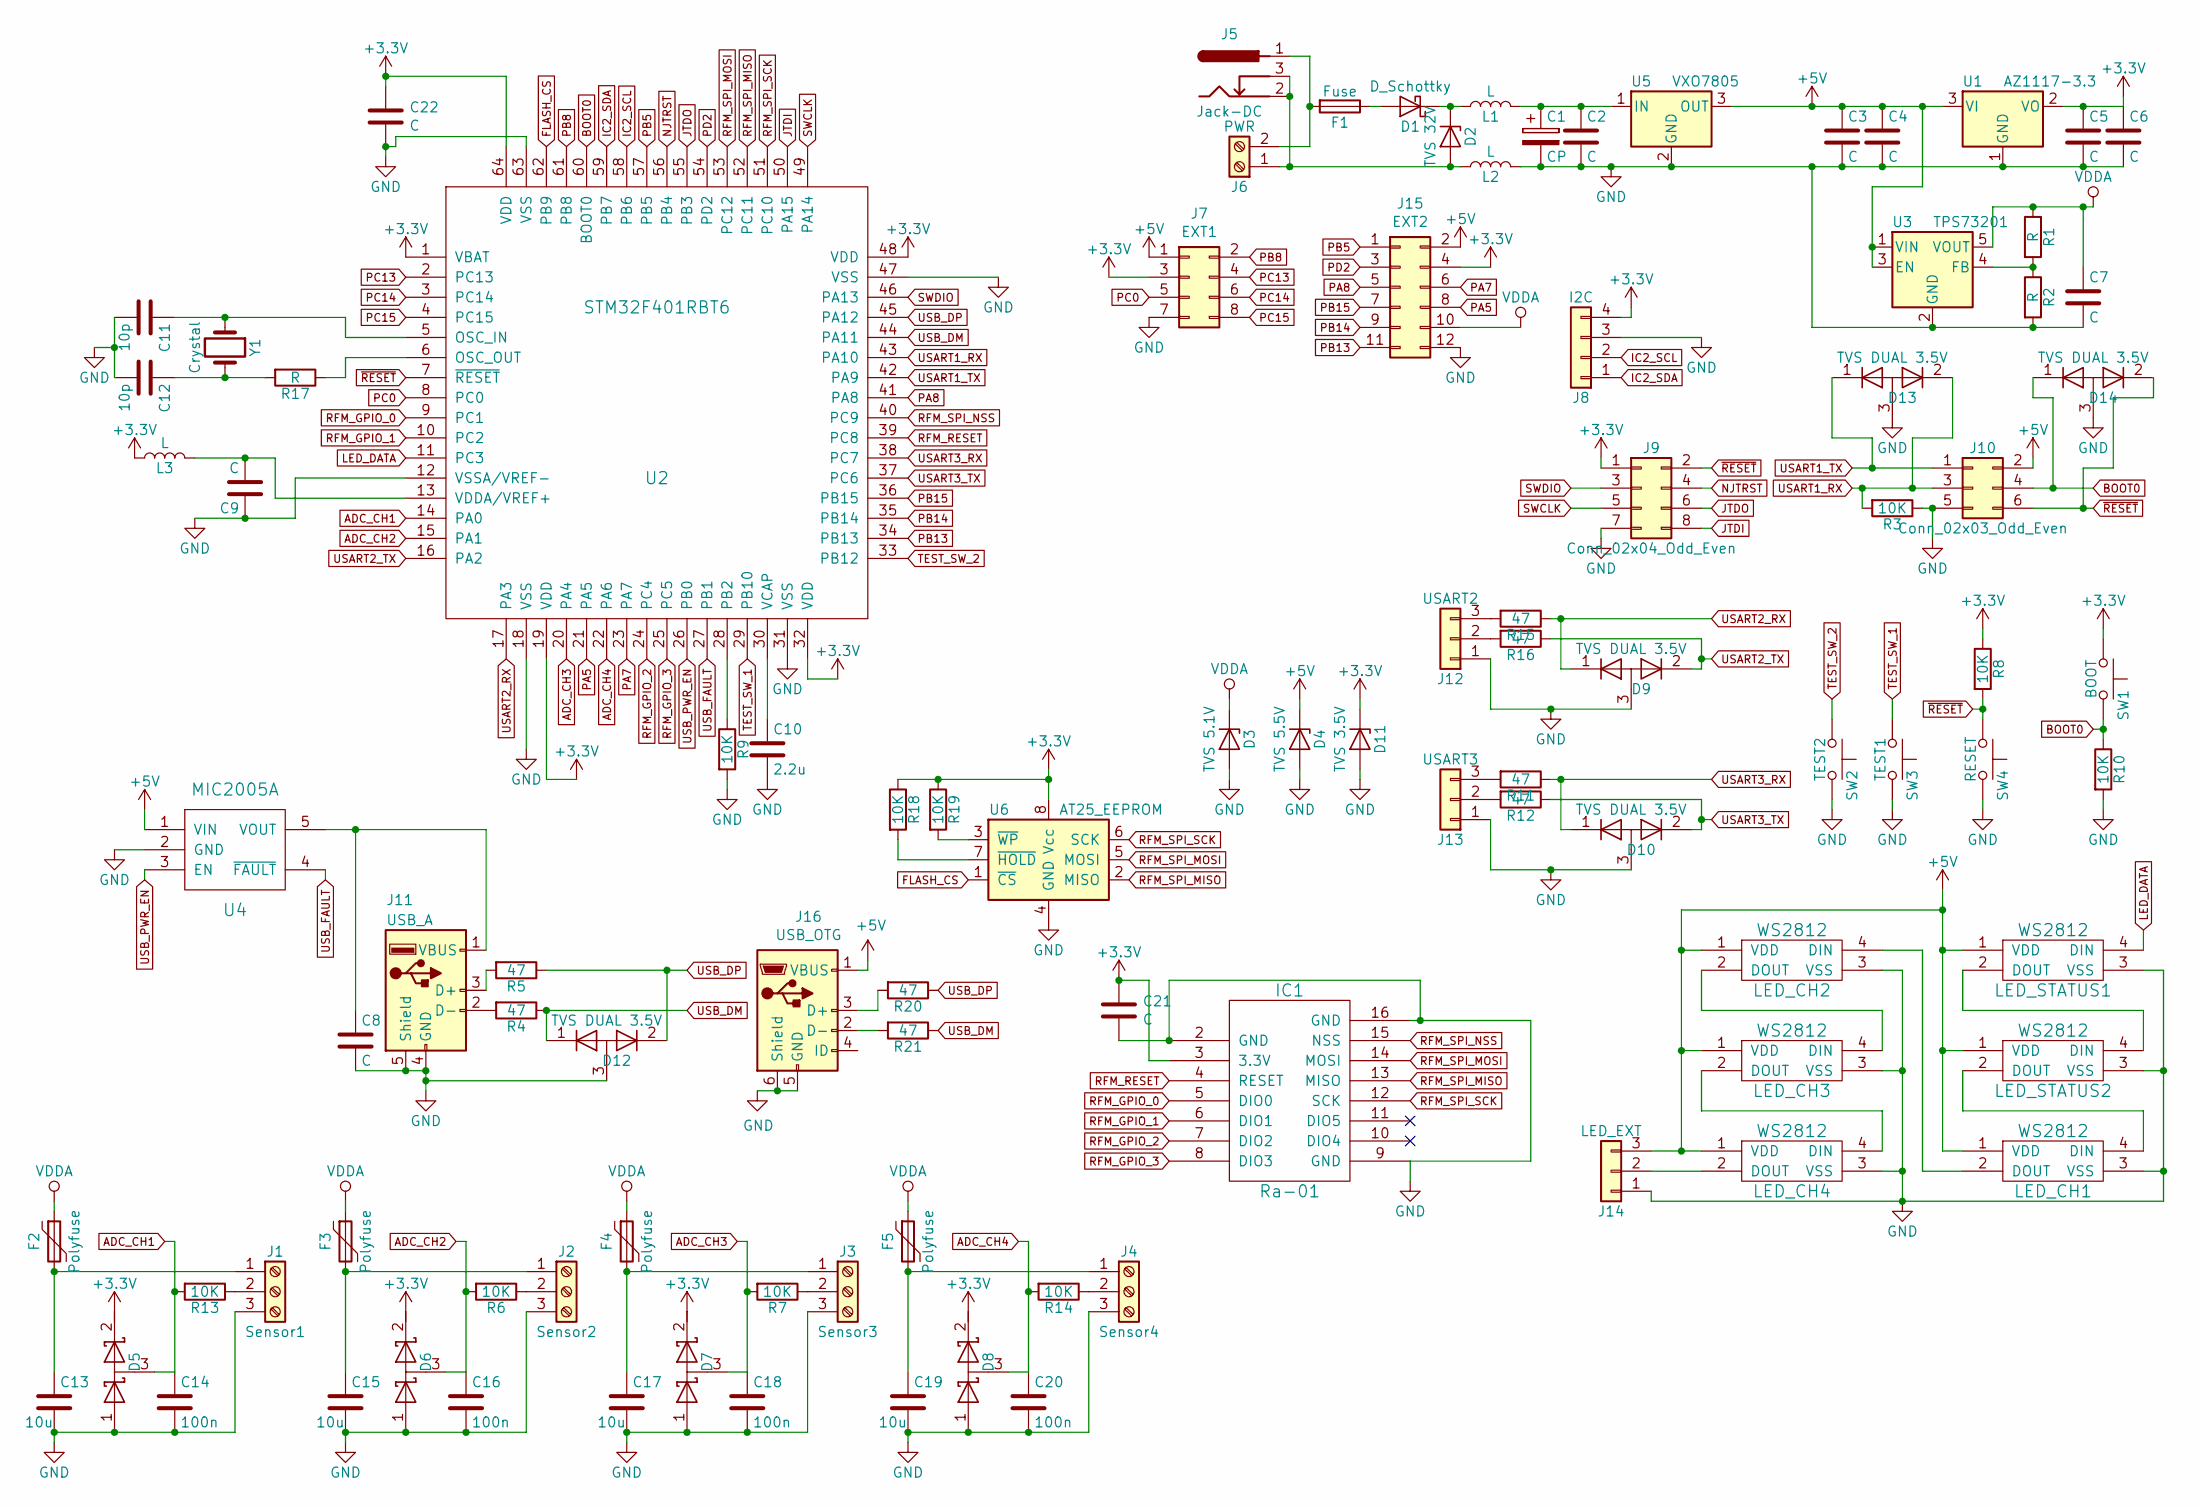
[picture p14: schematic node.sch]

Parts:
C1: CP; CP_Radial_D10.0mm_P5.00mm
C2, C3, C5, C21, C22: C; C_0805
C4, C6, C7, C8, C9: C; C_1206
C10: 2.2u; C_0805
C11, C12: 10p; C_0805
C13, C15, C17, C19: 10u; C_0805
C14, C16, C18, C20: 100n; C_0805
D1: D_Schottky; D_SOD-323
D2: TVS 32V; D_2010
D3: TVS 5.1V; D_SOD-323
D4: TVS 5.5V; D_SOD-323
D5, D6, D7, D8: D_Schottky_x2_Serial_AKC; SOT-23
D9, D10, D12, D13, D14: TVS DUAL 3.5V; SOT-23
D11: TVS 3.5V; D_SOD-323
F1: Fuse; Fuse_SMD
F2, F3, F4, F5: Polyfuse; SMD-1210_Pol
IC1: Ra-01
J1: Sensor1; Ampernol_3_3.5_hor
J2: Sensor2; Ampernol_3_3.5_hor
J3: Sensor3; Ampernol_3_3.5_hor
J4: Sensor4; Ampernol_3_3.5_hor
J5: Jack-DC; BARREL_JACK
J6: PWR; TerminalBlock_4UCON_19963_02x3.5mm_Straight
J7: EXT1; Pin_Header_Straight_2x04_Pitch2.54mm
J8: I2C; Pin_Header_Straight_1x04_Pitch2.54mm
J9: Conn_02x04_Odd_Even; Pin_Header_Straight_2x04_Pitch2.54mm
J10: Conn_02x03_Odd_Even; Pin_Header_Straight_2x03_Pitch2.54mm
J11: USB_A; USB_F_VERT
J12: USART2; Pin_Header_Straight_1x03_Pitch2.54mm
J13: USART3; Pin_Header_Straight_1x03_Pitch2.54mm
J14: LED_EXT; Pin_Header_Straight_1x03_Pitch2.54mm
J15: EXT2; Pin_Header_Straight_2x06_Pitch2.54mm
J16: USB_OTG; USB_Micro-B_10103594-0001LF
L1, L2, L3: L; Choke_SMD_1206_Standard
LED_CH1, LED_CH2, LED_CH3, LED_CH4: WS2812; LED_WS2812B-PLCC4
LED_STATUS1, LED_STATUS2: WS2812; LED_WS2812B-PLCC4
R1, R2, R17: R; R_0805
R3, R6, R7, R8, R9, R10, R13, R14, R18, R19: 10K; R_0805
R4, R5, R11, R12, R15, R16, R20, R21: 47; R_0805
SW1: BOOT; SW_SPST_PTS645
SW2: TEST2; SW_SPST_PTS645
SW3: TEST1; SW_SPST_PTS645
SW4: RESET; SW_SPST_PTS645
U1: AZ1117-3.3; SOT-223-3Lead_TabPin2
U2: STM32F401RBT6; LQFP-64_10x10mm_Pitch0.5mm
U3: TPS73201; SOT-23-5
U4: MIC2005A; SOT-23-5
U5: VXO7805; TO-220_Vertical
U6: AT25_EEPROM; SOIC-8_3.9x4.9mm_Pitch1.27mm
Y1: Crystal; Crystal_SMD_HC49-SD

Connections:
+3V3: C5.1, C6.1, C21.1, C22.1, D5.2 (K), D6.2 (K), D7.2 (K), D8.2 (K), D11.1 (K), IC1.3 (3.3V), J7.3, J8.4, J9.1, J15.4, L3.1, R8.1, R18.1, R19.1, SW1.1, U1.2 (VO), U2.1 (VBAT), U2.19 (VDD), U2.32 (VDD), U2.48 (VDD), U2.64 (VDD), U6.8 (Vcc)
+5V: C3.1, C4.1, D4.1 (K), J7.1, J10.2, J14.3, J15.2, J16.1 (VBUS), LED_CH1.1 (VDD), LED_CH2.1 (VDD), LED_CH3.1 (VDD), LED_CH4.1 (VDD), LED_STATUS1.1 (VDD), LED_STATUS2.1 (VDD), U1.3 (VI), U3.1 (VIN), U3.3 (EN), U4.1 (VIN), U5.3 (OUT)
ADC_CH1: C14.1, D5.3 (common), R13.2, U2.14 (PA0)
ADC_CH2: C16.1, D6.3 (common), R6.2, U2.15 (PA1)
ADC_CH3: C18.1, D7.3 (common), R7.2, U2.20 (PA4)
ADC_CH4: C20.1, D8.3 (common), R14.2, U2.22 (PA6)
BOOT0: D14.1 (K), J10.4, R10.1, SW1.2, U2.60 (BOOT0)
FLASH_CS: U2.62 (PB9), U6.1 (~CS)
GND: C1.2, C2.2, C3.2, C4.2, C5.2, C6.2, C7.2, C8.2, C9.1, C10.2, C11.2, C12.2, C13.2, C14.2, C15.2, C16.2, C17.2, C18.2, C19.2, C20.2, C21.2, C22.2, D3.2 (A), D4.2 (A), D5.1 (A), D6.1 (A), D7.1 (A), D8.1 (A), D9.3 (A), D10.3 (A), D11.2 (A), D12.3 (A), D13.3 (A), D14.3 (A), IC1.2 (GND), IC1.9 (GND), IC1.16 (GND), J1.3, J2.3, J3.3, J4.3, J7.7, J8.3, J9.7, J10.5, J11.4 (GND), J11.5 (Shield), J12.1, J13.1, J14.1, J15.12, J16.5 (GND), J16.6 (Shield), L2.2, LED_CH1.3 (VSS), LED_CH2.3 (VSS), LED_CH3.3 (VSS), LED_CH4.3 (VSS), LED_STATUS1.3 (VSS), LED_STATUS2.3 (VSS), R2.2, R3.1, R9.2, R10.2, SW2.2, SW3.2, SW4.2, U1.1 (GND), U2.12 (VSSA/VREF-), U2.18 (VSS), U2.31 (VSS), U2.47 (VSS), U2.63 (VSS), U3.2 (GND), U4.2 (GND), U5.2 (GND), U6.4 (GND)
IC2_SCL: J8.2, U2.58 (PB6)
IC2_SDA: J8.1, U2.59 (PB7)
JTDI: J9.8, U2.50 (PA15)
JTDO: J9.6, U2.55 (PB3)
LED_DATA: LED_STATUS1.4 (DIN), U2.11 (PC3)
NJTRST: J9.4, U2.56 (PB4)
unnamed: C1.1, C2.1, L1.2, U5.1 (IN)
unnamed: C8.1, J11.1 (VBUS), U4.5 (VOUT)
unnamed: C9.2, L3.2, U2.13 (VDDA/VREF+)
unnamed: C10.1, U2.30 (VCAP)
unnamed: C11.1, U2.5 (OSC_IN), Y1.1
unnamed: C12.1, R17.2, Y1.2
unnamed: C13.1, F2.2, J1.1
unnamed: C15.1, F3.2, J2.1
unnamed: C17.1, F4.2, J3.1
unnamed: C19.1, F5.2, J4.1
unnamed: D1.1 (K), D2.1 (K), L1.1
unnamed: D1.2 (A), F1.1
unnamed: D2.2 (A), J5.2, J5.3, J6.1, L2.1
unnamed: F1.2, J5.1, J6.2
unnamed: J1.2, R13.1
unnamed: J2.2, R6.1
unnamed: J3.2, R7.1
unnamed: J4.2, R14.1
unnamed: J11.2 (D-), R4.2
unnamed: J11.3 (D+), R5.2
unnamed: J12.2, R16.2
unnamed: J12.3, R15.2
unnamed: J13.2, R12.2
unnamed: J13.3, R11.2
unnamed: J14.2, LED_CH4.2 (DOUT)
unnamed: J16.2 (D-), R21.2
unnamed: J16.3 (D+), R20.2
unnamed: LED_CH1.2 (DOUT), LED_CH2.4 (DIN)
unnamed: LED_CH1.4 (DIN), LED_STATUS2.2 (DOUT)
unnamed: LED_CH2.2 (DOUT), LED_CH3.4 (DIN)
unnamed: LED_CH3.2 (DOUT), LED_CH4.4 (DIN)
unnamed: LED_STATUS1.2 (DOUT), LED_STATUS2.4 (DIN)
unnamed: R1.2, R2.1, U3.4 (FB)
unnamed: R9.1, U2.28 (PB2)
unnamed: R17.1, U2.6 (OSC_OUT)
unnamed: R18.2, U6.7 (~HOLD)
unnamed: R19.2, U6.3 (~WP)
PA5: J15.8, U2.21 (PA5)
PA7: J15.6, U2.23 (PA7)
PA8: J15.5, U2.41 (PA8)
PB5: J15.1, U2.57 (PB5)
PB8: J7.2, U2.61 (PB8)
PB13: J15.11, U2.34 (PB13)
PB14: J15.9, U2.35 (PB14)
PB15: J15.7, U2.36 (PB15)
PC0: J7.5, U2.8 (PC0)
PC13: J7.4, U2.2 (PC13)
PC14: J7.6, U2.3 (PC14)
PC15: J7.8, U2.4 (PC15)
PD2: J15.3, U2.54 (PD2)
RFM_GPIO_0: IC1.5 (DIO0), U2.9 (PC1)
RFM_GPIO_1: IC1.6 (DIO1), U2.10 (PC2)
RFM_GPIO_2: IC1.7 (DIO2), U2.24 (PC4)
RFM_GPIO_3: IC1.8 (DIO3), U2.25 (PC5)
RFM_RESET: IC1.4 (RESET), U2.39 (PC8)
RFM_SPI_MISO: IC1.13 (MISO), U2.52 (PC11), U6.2 (MISO)
RFM_SPI_MOSI: IC1.14 (MOSI), U2.53 (PC12), U6.5 (MOSI)
RFM_SPI_NSS: IC1.15 (NSS), U2.40 (PC9)
RFM_SPI_SCK: IC1.12 (SCK), U2.51 (PC10), U6.6 (SCK)
SWCLK: J9.5, U2.49 (PA14)
SWDIO: J9.3, U2.46 (PA13)
TEST_SW_1: SW3.1, U2.29 (PB10)
TEST_SW_2: SW2.1, U2.33 (PB12)
USART1_RX: D13.2 (K), J10.3, R3.2, U2.43 (PA10)
USART1_TX: D13.1 (K), J10.1, U2.42 (PA9)
USART2_RX: D9.1 (K), R15.1, U2.17 (PA3)
USART2_TX: D9.2 (K), R16.1, U2.16 (PA2)
USART3_RX: D10.1 (K), R11.1, U2.38 (PC7)
USART3_TX: D10.2 (K), R12.1, U2.37 (PC6)
USB_DM: D12.1 (K), R4.1, R21.1, U2.44 (PA11)
USB_DP: D12.2 (K), R5.1, R20.1, U2.45 (PA12)
USB_FAULT: U2.27 (PB1), U4.4 (~FAULT)
USB_PWR_EN: U2.26 (PB0), U4.3 (EN)
VDDA: C7.1, D3.1 (K), F2.1, F3.1, F4.1, F5.1, J15.10, R1.1, U3.5 (VOUT)
~RESET: D14.2 (K), J9.2, J10.6, R8.2, SW4.1, U2.7 (~RESET)

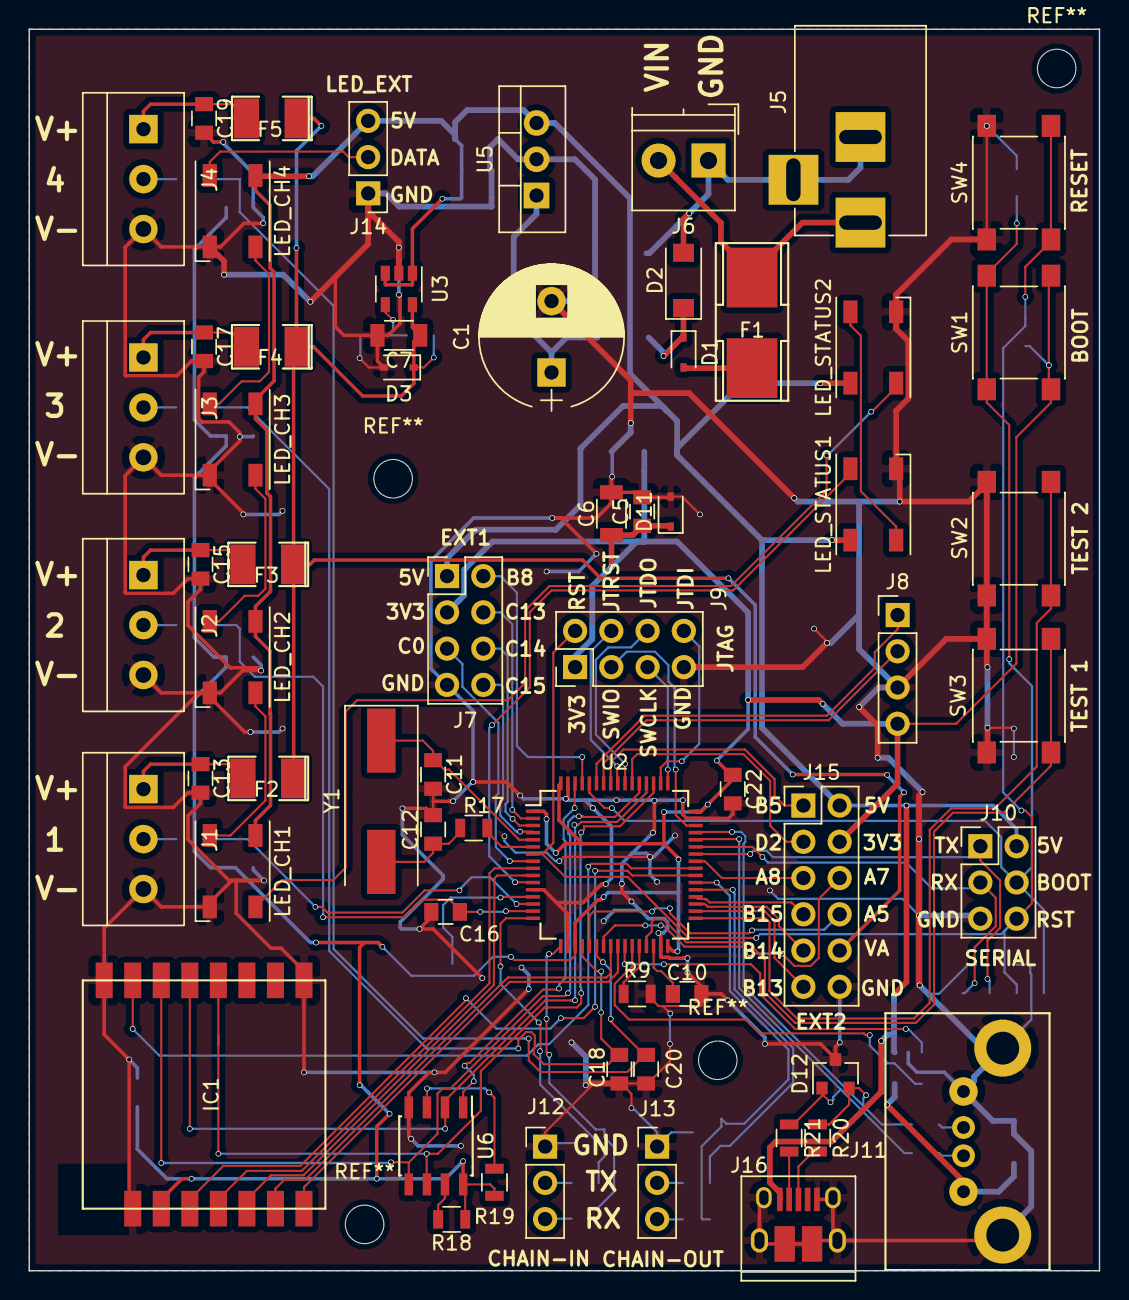
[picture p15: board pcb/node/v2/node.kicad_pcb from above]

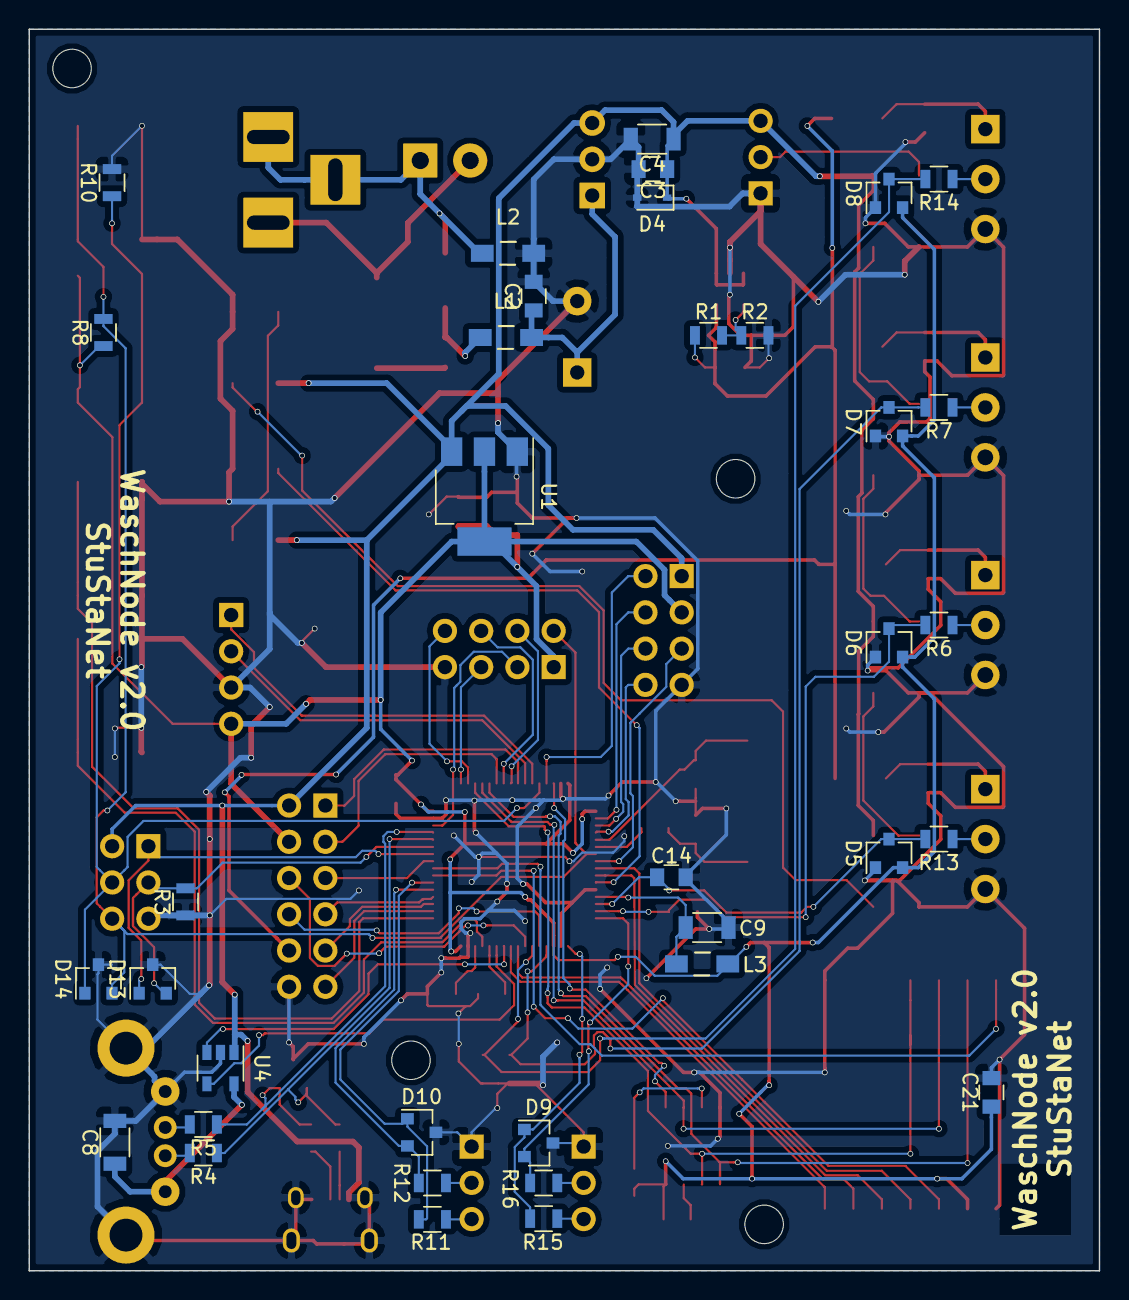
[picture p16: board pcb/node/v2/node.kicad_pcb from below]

Board: 2 copper layers, 75.0 x 87.0 mm, 99 parts (36 on the bottom side), 90 nets.

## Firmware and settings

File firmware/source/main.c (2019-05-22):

/*
 * Copyright 2018 Daniel Frejek
 * This source code is licensed under the MIT license that can be found
 * in the LICENSE file.
 */


#include <stdio.h>
#include <stdlib.h>
#include <string.h>

#include <libopencm3/stm32/rcc.h>
#include <libopencm3/stm32/gpio.h>
#include <libopencm3/stm32/usart.h>
#include <libopencm3/stm32/timer.h>
#include <libopencm3/stm32/flash.h>
#include <libopencm3/stm32/adc.h>
#include <libopencm3/cm3/cortex.h>

#include <FreeRTOS.h>
#include <task.h>

#include "tinyprintf.h"
#include "serial_getchar_dma.h"
#include "cli.h"
#include "commands_common.h"
#include "meshnw.h"
#include "isrsafe_printf.h"

#if !defined(MASTER) && defined(WASCHV2)
#include "debug_command_queue.h"
#endif

#ifdef WASCHV2
// Clock for the STM32F401
const struct rcc_clock_scale hse_8_84mhz =
{
	.pllm = 4,     // PLL input is 2MHz
	.plln = 168,   // PLL output is 336 MHz
	.pllp = 4,     // CPU clock 84 MHz
	.pllq = 7,     // USB clock 48MHz
	.hpre = RCC_CFGR_HPRE_DIV_NONE,
	.ppre1 = RCC_CFGR_PPRE_DIV_2,
	.ppre2 = RCC_CFGR_PPRE_DIV_NONE,
	.flash_config = FLASH_ACR_ICEN | FLASH_ACR_DCEN | FLASH_ACR_LATENCY_2WS,
	.ahb_frequency  = 84000000,
	.apb1_frequency = 42000000,
	.apb2_frequency = 84000000,
};

#define CLOCK_SETTINGS hse_8_84mhz
#endif

// Stack size in words for the CLI task
#define CLI_TASK_STACK_SIZE 512

// Number of bytes in the command buffer for the CLI
// This resides on the stack of the CLI task so keep the stack size in mind when changing this!
#define CLI_CMD_BUFFER_LENGTH 200

#define USART_CLI USART1
#define USART_CLI_RCC RCC_USART1

StaticTask_t cliTaskBuffer;
StackType_t cliTaskStack[CLI_TASK_STACK_SIZE];

void node_init(void);
extern cli_command_t cli_commands [];

static void tpf_putcf(void *ptr, char c)
{
	(void)ptr;
	usart_send_blocking(USART_CLI, c);
}


static void init_usart(void)
{
	rcc_periph_clock_enable(RCC_GPIOA);
	rcc_periph_clock_enable(USART_CLI_RCC);

#ifdef WASCHV2
	gpio_mode_setup(GPIOA, GPIO_MODE_AF, GPIO_PUPD_NONE, GPIO9 | GPIO10);
	gpio_set_af(GPIOA, GPIO_AF7, GPIO9 | GPIO10);
#else
	gpio_set_mode(GPIOA, GPIO_MODE_OUTPUT_50_MHZ, GPIO_CNF_OUTPUT_ALTFN_PUSHPULL, GPIO_USART1_TX);

	// On the V1 borads, the status LED of the bluepill board is connected to this pin
	// => Switch on this LED
	rcc_periph_clock_enable(RCC_GPIOC);
	gpio_set_mode(GPIOC, GPIO_MODE_OUTPUT_50_MHZ, GPIO_CNF_OUTPUT_PUSHPULL, GPIO13);
	gpio_clear(GPIOC, GPIO13);
#endif

	usart_set_baudrate(USART_CLI, 115200);
	usart_set_mode(USART_CLI, USART_MODE_TX | USART_MODE_RX);
	usart_enable(USART_CLI);
}


static void cliTask(void *arg)
{
	(void) arg;

	char buffer[CLI_CMD_BUFFER_LENGTH];
	size_t buffer_pos = 0;

	cli_set_commandlist(cli_commands);

	while (1)
	{

#if !defined(MASTER) && defined(WASCHV2)
		if (debug_command_queue_running())
		{
			char *next = debug_command_queue_next();

			if (next)
			{
				cli_evaluate(next);
				continue;
			}
		}
#endif
		int16_t c = serial_getchar();

		if (c == INT16_MIN)
		{
			taskYIELD();
			continue;
		}

		if (c == '\r' || c == '\n' || buffer_pos >= (CLI_CMD_BUFFER_LENGTH - 1))
		{
			if (buffer_pos)
			{
				buffer[buffer_pos] = 0;
				cli_evaluate(buffer);
				buffer_pos = 0;
#ifdef CLI_PROMPT
				ISRSAFE_PRINTF(CLI_PROMPT);
#endif
			}
		}
		else
		{
			buffer[buffer_pos] = c;
			buffer_pos++;
		}
	}
}


int main(void)
{
	cm_disable_interrupts();
#ifdef WASCHV2
	rcc_clock_setup_hse_3v3(&CLOCK_SETTINGS);
#else
	rcc_clock_setup_in_hse_8mhz_out_72mhz();
#endif

	init_usart();
	serial_getchar_dma_init();
	init_printf(NULL, &tpf_putcf);

	printf("Wasch node starting...\n");
	node_init();

	xTaskCreateStatic(
		&cliTask,
		"CLI",
		CLI_TASK_STACK_SIZE,
		NULL,
		tskIDLE_PRIORITY,
		cliTaskStack,
		&cliTaskBuffer);


	vTaskStartScheduler();

	return 0;
}


// From https://www.freertos.org/a00110.html
void vApplicationGetIdleTaskMemory( StaticTask_t **ppxIdleTaskTCBBuffer,
                                    StackType_t **ppxIdleTaskStackBuffer,
                                    uint32_t *pulIdleTaskStackSize )
{
	static StaticTask_t xIdleTaskTCB;
	static StackType_t uxIdleTaskStack[ configMINIMAL_STACK_SIZE ];

    *ppxIdleTaskTCBBuffer = &xIdleTaskTCB;
    *ppxIdleTaskStackBuffer = uxIdleTaskStack;
    *pulIdleTaskStackSize = configMINIMAL_STACK_SIZE;
}

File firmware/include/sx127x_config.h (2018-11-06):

/*
 * Copyright 2018 Daniel Frejek
 * This source code is licensed under the MIT license that can be found
 * in the LICENSE file.
 */

#pragma once

#include <libopencm3/stm32/rcc.h>
#include <libopencm3/stm32/gpio.h>
#include <libopencm3/stm32/spi.h>

#if defined(WASCHV1)

#define SX127X_SPI               SPI1
#define SX127X_SPI_RCC           RCC_SPI1
#define SX127X_SPI_GPIO_RCC      RCC_GPIOA
#define SX127X_SPI_GPIO_PORT     GPIOA
#define SX127X_SPI_GPIO_PIN_MOSI GPIO7
#define SX127X_SPI_GPIO_PIN_MISO GPIO6
#define SX127X_SPI_GPIO_PIN_SCK  GPIO5
#define SX127X_SPI_GPIO_PIN_NSS  GPIO4

#define SX127X_RESET_GPIO_RCC    RCC_GPIOC
#define SX127X_RESET_GPIO_PORT   GPIOC
#define SX127X_RESET_GPIO_PIN    GPIO15

#else

#define SX127X_SPI               SPI3
#define SX127X_SPI_RCC           RCC_SPI3
#define SX127X_SPI_GPIO_RCC      RCC_GPIOC
#define SX127X_SPI_GPIO_PORT     GPIOC
#define SX127X_SPI_GPIO_PIN_MOSI GPIO12
#define SX127X_SPI_GPIO_PIN_MISO GPIO11
#define SX127X_SPI_GPIO_PIN_SCK  GPIO10
#define SX127X_SPI_GPIO_PIN_AF   GPIO_AF6
#define SX127X_SPI_GPIO_PIN_NSS  GPIO9

#define SX127X_RESET_GPIO_RCC    RCC_GPIOC
#define SX127X_RESET_GPIO_PORT   GPIOC
#define SX127X_RESET_GPIO_PIN    GPIO8

#endif

// SPI3 is on the APB1 bus which is clocked at 42MHz
// The max allowed frequency is 10 MHz so we need a 8 divider (SPI has an internal 2 divider)
#define SX127X_SPI_BAUDRATE      SPI_CR1_BAUDRATE_FPCLK_DIV_8

// Module configuration
// 32 MHz
#define SX127X_CONFIG_FXOSC 32000000

// Set to 1 if the antenna is connected to the boost pin
#define SX127X_USE_PA_BOOST_PIN 1

// Allowed paramenter ranges
// See the SX127X datasheet for details.
#define SX127X_CONFIG_LORA_SPREAD_MAX    12
#define SX127X_CONFIG_LORA_SPREAD_MIN    7
#define SX127X_CONFIG_LORA_CODERATE_MAX  3
#define SX127X_CONFIG_LORA_BW_MAX  9


// TX Power in db (regulatory limit for Germany: max 10db (10 mW))
#define SX127X_CONFIG_LORA_POWER_MAX     10


// Freqency limitations to stay within German regulatury limitations
#define SX127X_CONFIG_LORA_FREQUENCY_MIN 433200000
#define SX127X_CONFIG_LORA_FREQUENCY_MAX 434600000

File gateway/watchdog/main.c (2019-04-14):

/*
 * Copyright 2018 Daniel Frejek
 * This source code is licensed under the MIT license that can be found
 * in the LICENSE file.
 */

#include <avr/io.h>
#include <avr/interrupt.h>
#include <avr/wdt.h>
#include <util/delay.h>
#include <stdlib.h>
#include <stdint.h>


#ifndef F_CPU
#error "F_CPU is not defined"
#endif


// At 11.0592 MHz, this is exactly 115200 baud
#define BAUDRATE_DIVIDER_L 5
#define BAUDRATE_DIVIDER_H 0

// 5 Min
#define WATCHDOG_TIMEOUT_SEC (300UL)

// 30 sec before the reset, we assert a 'prefail' signal
// This allows the host to send / log, that the reset was caused by the watchdog.
#define PREFAIL_THRESHOLD_SEC (270UL)

#define RESET_PULSE_LENGTH_MS (3000)


// 256 from the prescaler * 256 from the counter
#define WATCHDOG_DIVIDER (256UL * 256UL)

#define WATCHDOG_COUNTER_MAX ((WATCHDOG_TIMEOUT_SEC * F_CPU) / WATCHDOG_DIVIDER)
#define WATCHDOG_COUNTER_PREFAIL ((PREFAIL_THRESHOLD_SEC * F_CPU) / WATCHDOG_DIVIDER)

#define RESET_OUTPUT_PORT PORTB
#define RESET_OUTPUT_DDR DDRB
#define RESET_OUTPUT_PIN PB0

#define PREFAIL_OUTPUT_PORT PORTD
#define PREFAIL_OUTPUT_DDR DDRD
#define PREFAIL_OUTPUT_PIN PD6

volatile uint32_t watchdog_counter;


void init_uart()
{
	// RX only, 8N1
	UBRRH = BAUDRATE_DIVIDER_H;
	UBRRL = BAUDRATE_DIVIDER_L;
	UCSRB = (1 << RXEN) | (1 << TXEN);
	UCSRC = (1 << UCSZ1) | (1 << UCSZ0);
}


void init_timer()
{
	TCCR0A = 0;
	TCCR0B = (1 << CS02); // Prescaler 256
	TIMSK = (1 << TOIE0);
}


// Reset the host device
// NOTE: The AVRs watchdog needs to be reset while this is running!
void send_reset_pulse()
{
	RESET_OUTPUT_DDR |= (1 << RESET_OUTPUT_PIN);
	RESET_OUTPUT_PORT |= (1 << RESET_OUTPUT_PIN);
	_delay_ms(RESET_PULSE_LENGTH_MS);
	RESET_OUTPUT_PORT &= ~(1 << RESET_OUTPUT_PIN);
}


void putch(char c)
{
	while (!(UCSRA & (1 << UDRE)));
    UDR = c;
}


void putstr(const char *s)
{
	while (*s)
	{
		putch(*s);
		s++;
	}
}


void wait_for_food()
{
	static const uint8_t *FEED_STRING = "wdt_feed";

	const uint8_t *cmp_ptr = FEED_STRING;

	while (*cmp_ptr)
	{
		while (!(UCSRA & (1 << RXC)));
		uint8_t ch = UDR;

		if (ch == *cmp_ptr)
		{
			// OK -> next char
			cmp_ptr++;
		}
		else
		{
			// Wrong -> reset
			cmp_ptr = FEED_STRING;
		}
	}
}


int main (void)
{
	wdt_reset();
	watchdog_counter = 0;
	init_uart();
	init_timer();
	sei();
	wdt_reset();
	putstr("Watchdog started -- sending reset pulse\n");

	PREFAIL_OUTPUT_DDR |= (1 << PREFAIL_OUTPUT_PIN);

	// Begin with a reset pulse
	send_reset_pulse();

	while (1)
	{
		wait_for_food();
		putstr("OK\n");
		watchdog_counter = 0;
	}
}



ISR (TIMER0_OVF_vect)
{
	if (watchdog_counter > WATCHDOG_COUNTER_MAX)
	{
		putch('!');
	}
	else
	{
		wdt_reset();
		watchdog_counter++;
	}

	if (watchdog_counter > WATCHDOG_COUNTER_PREFAIL)
	{
		PREFAIL_OUTPUT_PORT |= (1 << PREFAIL_OUTPUT_PIN);
	}
	else
	{
		PREFAIL_OUTPUT_PORT &= ~(1 << PREFAIL_OUTPUT_PIN);
	}
}

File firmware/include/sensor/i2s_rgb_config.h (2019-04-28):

/*
 * The PLL and clock dividers for the I2S has to be configured so that the resulting bit clock is 3 times (WS2812) or 4 times (SK6812)
 * the bit clock for the LEDs.
 */

#include <libopencm3/stm32/gpio.h>
#include <libopencm3/stm32/dma.h>
#include <libopencm3/stm32/rcc.h>
#include <libopencm3/stm32/spi.h>
#include "led_status.h"

// The PLL has an input frequency of 1 - 2 MHz (Usually 2MHz).
// With this multiplier, the PLL Output frequency has to be set to a value
// in the range of 100 - 432 MHz.
// Valid range for this value is [50 - 432]
#define I2RGB_I2S_PLL_MUL 125

// This is the after-pll divider, it has to ensure, that the output frequency is < 192MHz.
// Valid range for this value is [2 - 7]
#define I2RGB_I2S_PLL_DIV 2

// This is the 'final' divider inside the I2S peripheral
// It defines the bitclock for the output signal
// Valid range for this value is [4 - 511]
// NOTE: Internally, the value is split into a 8-bit value (which defines 2 * the divider)
//       and an 'odd' bit, which defines the lowest bit.
//       For this value both fields are combined in a single value.
#define I2RGB_I2S_CLK_DIV 50


#define I2RGB_SPI SPI2
#define I2RGB_SPI_RCC RCC_SPI2
#define I2RGB_SPI_GPIO_RCC RCC_GPIOC
#define I2RGB_SPI_GPIO_PORT GPIOC
#define I2RGB_SPI_GPIO_PIN  GPIO3
#define I2RGB_SPI_GPIO_PIN_AF GPIO_AF5

#define I2RGB_DMA DMA1
#define I2RGB_DMA_RCC RCC_DMA1
// Channel (request) for SPI
#define I2RGB_DMA_CHANNEL DMA_SxCR_CHSEL_0
// Stream for the SPI
#define I2RGB_DMA_STREAM 4

#define WS2812 0
#define SK6812 1

// Timing mode
#define I2RGB_TIMING WS2812

// Num of LEDs
#define I2RGB_NUM_OF_LEDS NUM_OF_LEDS

// Bytes per LED
#define I2RGB_BYTES_PER_LED 3

// Number of bits for the break in input bits
#define I2RGB_NUM_BREAK_BITS 80

#define I2RGB_DMA_MODE_NO_DMA 0
#define I2RGB_DMA_MODE_SINGLE 1
#define I2RGB_DMA_MODE_CONTINOUS 2

#define I2RGB_DMA_MODE I2RGB_DMA_MODE_SINGLE

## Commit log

2017-07-09 Added rftest project
    [gdb_init.cfg]
2017-07-09 Added sensor information
    [amp.sch]
2017-07-09 Fixed RFM26 driver (and updated / fixed ll debug code)
2017-07-12 Added simple LED status output for rf range testing
2017-07-22 Added some adc test code
    [gdb_init.cfg]
2017-07-22 Added schematic svg image
2017-08-30 Added RIOT based adc test application
2017-10-22 layout for sensor
    [amp.sch]
2017-10-22 missing stuff
    [amp.kicad_pcb]
2017-10-23 added node hardware layout
    [node.kicad_pcb, node.sch]
2017-10-25 Better Layout + added extension headers
    [node.kicad_pcb, node.sch]
2017-10-25 Added gerbers dir to gitignore
2017-10-25 Added layout border
    [amp.kicad_pcb]
2017-10-25 Remove now obsolete libopencm3 based stuff
    [gdb_init.cfg]
2017-11-08 Main for sensor node
2017-11-13 Increased stack size for mesh thread and set tx power
2017-11-13 Increased stack sizes + various changes on the sensor node i'm too lazy to seperate.
2017-11-13 Only build sensor_config if not master
2017-11-13 Added sensor connection functions
2017-11-13 Sensor config command is config, not cfg
2017-11-14 Added some debug commands to sensor node
2017-11-19 Removed automatic retransmissions to avoid congestion if multiple nodes are connected
    [main.c]
2017-11-19 Added RIOT board definition for bluepill board
2017-11-22 Added waiting for a response in order to avoid jamming the network
    [main.py]
2017-11-30 Added timeout for sensor node
2017-12-03 added sensor casing, main casing and cable support cad
    [cable.scad, casing.scad, logo.dxf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]
2017-12-06 increased height of upper casing to account for the printed support
    [main_casing.scad]
2017-12-19 Added LED support
2018-01-02 Missing ws2801 driver
2018-01-02 RF frequency and tx power are now configureable for the sensor node
2018-01-02 Added LED animation
2018-01-04 Use own board "wasch_v1" and fixed build for current RIOT version
2018-01-04 Forgot to add "wasch_v1" board
2018-01-04 More fixes for new driver version
2018-01-07 added accessor functon for the current state
2018-01-07 Added "print_frames" debug command
2018-01-07 Added message with id to sensor init
2018-01-17 Print node id on LEDs on startup
2018-01-20 Added DMA based getchar implementation
2018-01-20 use dma getchar
2018-01-21 Added adc thread watchdog
2018-01-21 Reduced adc thread stack (has no auth)
2018-01-21 Changed adc thread prio to max to avoid xtimer bug
2018-02-07 Fixed tx power settingC
2018-02-08 Periodically re-set the LEDs
2018-02-08 Fixed sensor status being wrong after reinit
2018-02-08 Fixed sensor status being wrong after reinit, missing file
2018-02-08 Status print is now ISR safe
2018-02-10 Removed superflous delay in LED code
2018-02-10 Set unititialized LEDs to 0
2018-03-07 Added filter description to README
2018-03-08 added a testing framework with socat
2018-03-08 fixed error in debuginterface
    [debuginterface.py]
2018-03-08 added frames, status, led, shutdown to debuginterface
2018-04-07 Activate forwaring if routes on a sensor are manually set
2018-04-24 Added license headers and fixed some typos
    [main.c]
2018-08-23 added longely standing around parts
    [distance_wall.scad, parts.ods, sensor_wall_plate.scad]
2018-10-15 Split project into master and sensor part
2018-10-17 Added DMA for the USART
2018-10-19 Added sx127x driver
2018-10-19 Sx127x driver test
2018-10-20 Thread function should not return a value
2018-10-20 Added build files for sensor node and ported led lib
2018-10-20 Ported sensor config
2018-10-20 Added define for board version 2
2018-10-20 Ported sensor node and added ADC with DMA
2018-10-21 Ported master config and fixed build for legacy board
    [sx127x.c, sx127x_config.h]
2018-10-21 Master and sensor now build for both board variants
2018-10-21 I2S base led driver
2018-10-21 Fixed led status
2018-10-23 Added sx127x driver description
2018-10-23 Added usb_storage_helper wrapper for msc devices
2018-10-23 Added fatfs
    [mkfs.xls]
2018-10-23 Build USBH FS driver and fixed usbh debug
2018-10-23 Turn on the USB power
2018-10-23 Reduced prio and reset busy state on disconnect to avoid the poll thread blocking the CPU
2018-10-23 Currect LED status
2018-10-26 Fixed v1 sensor build
2018-10-28 Added frequency sensor
2018-10-28 Fixed wrong size of DMA transfer
2018-10-30 Fixed LEDs on legacy boards
2018-10-30 Don't dim external status LEDs
2018-11-01 Moved i2s led impl to own dir
2018-11-01 Implemented test buttons
2018-11-01 Added sanity check before enabling the sensor channel
2018-11-02 Fixed frequency sensor
2018-11-02 Fixed freq sensor for real now
2018-11-02 Fixed modem getting stuck in FSTX mode
    [sx127x.c]
2018-11-02 Added status print for freq channels
2018-11-06 Added v2 PCBs and updated v1 versions to KiCad 5
    [amp-2018-07-21-13-22-14.sch, amp-2018-11-06-12-48-31.sch, amp.kicad_pcb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]
2018-11-06 Removed old pcb files
    [amp.kicad_pcb, amp.sch, node.kicad_pcb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]
2018-11-06 Moved description files to sensor dir and removed duplicates
2018-11-06 Added schematic as pdf
2018-11-06 Added stm32loader submodule
2018-11-06 Moved old scad files to v1 and add new sensor design
    [cable.scad, casing.scad, distance_wall.scad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]
2018-11-07 Added missing part values
    [node.sch]
2018-11-25 Added led test command
2018-12-05 Added current mid value to debug print
2019-02-13 rewrote pyinterface to be a state machine
    [sensor_normal.cfg]
2019-02-13 added manhattan sensor. running tests
    [sensor_manhattan.cfg]
2019-02-13 Added current manhattan switch impl
2019-02-13 Fixed config
    [sensor_normal.cfg]
2019-02-13 Fixed device led state can be wrong if a status update happens before the LED update is confirmed
2019-02-13 Removed now obsolete files
    [sensor_manhattan.cfg, sensor_normal.cfg]
2019-02-13 Fixed master restart not resetting the node status
    [basenode.py, manhattannode.py, master.py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]
2019-02-13 Turn on status LED on V1 boards
2019-02-13 Fixed serial mode in master
    [master.py]
2019-02-14 Fixed LED update
2019-02-14 Fixed some problems of the debug interface
    [debuginterface.py]
2019-02-14 Also print response type to log
2019-04-14 Gateway must not force the reste line to 3.3v, otherwise the software reset of the mcu won't work
    [gateway.py]
2019-04-14 Added copy of stm32loader to the gateway
2019-04-18 Fixed controller hangup on debug interface disconnect
    [debuginterface.py]
2019-04-18 Fixed debug interface crash
    [debuginterface.py]
2019-04-28 Fixed external LEDs not being updated for v2 nodes
    [i2s_rgb_config.h, led_status.h]
2019-04-28 Status command now also prints if the channels are enabled
2019-04-28 Added modem reset, when the modem drops out of LoRa mode
    [sx127x.c]
2019-05-01 Normal nodes have 5 status LEDs
2019-05-04 Also print state dump on empty command
2019-05-05 Added HSH18 to led map
2019-06-10 Fixed frame value logging
2020-04-17 Removed LED command as it would invalidate the internal status
2020-04-17 Added retry command to manually reset the reconnect timeouts
    [basenode.py, debuginterface.py, master.py]
2020-05-02 Always print an error status when a command fails
2020-05-02 Fixed on ack status not being reset when a command fails
    [basenode.py, manhattannode.py, master.py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]
